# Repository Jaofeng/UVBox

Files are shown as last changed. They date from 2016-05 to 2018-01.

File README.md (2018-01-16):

# 自製 UV 紫外線曝光控制器
本控制器以 Arduino 的 ATMEGA328P 為核心，控制 UV LED 燈板，作為 DIY PCB 曝光用。

## 目錄
* [控制器硬體概要說明](#控制器硬體概要說明)
* [Arduino 程式功能](#arduino-程式功能)
* [原理圖與板線圖](#原理圖與板線圖)
* [實做範例](#實做範例)

## 控制器硬體概要說明
控制器分為兩版本：595 版與 I2C LCD 版。  
兩版本電路、功能都大同小異，最大差別在於 595 版是使用 74x595 控制七段顯示器作為顯示；I2C LCD 則是使用 PCF8574 控制 1602 的 LCD(相容HD44780)。  
I2C LCD 版提供 USB 界面(使用 FT232R)，可直接修改 Arduino 程式；而 595 版本就必須使用 ICSP 界面進行更新。

使用 4 + 1 個按鍵共 5 個按鍵進行控制：
* Start : 開始曝光
* Mode : 選擇模式  
    * 同時點亮上下兩板  
    * 僅點亮上板  
    * 僅點亮下板  
    * 亮度調整模式  
* Up / Dn :  
    * 亮度調整模式：增加/減少亮度值，增減量 +/- 5%
    * 其餘模式：增加/減少秒數，增減量 10 秒
* Reset : 重新啟動

595 版是第一個版本，小弟先用麵包版電路作第一片 595 版的 PCB，再用他去做其他的 PCB。

使用一般 Notebook 電源供應器(DC 19V)做為電源輸入，由於電路主要電壓使用 5V，為避免壓差太大，造成降壓晶片過熱燒毀，所以我做了兩次降壓：19v -> 12v -> 5v。  
由 ULN2003 控制 UV LED 燈板，也就是燈板部分直接使用 19V 電源。

在此不提供 UV LED 燈板的電路，我使用 5 串 1 並 14 的方式組成一片燈板，意思就是 5 顆 UV LED 與 1 顆限流電阻為一組做串聯，一共有 14 組併聯(請參閱下方照片)。    
LED 間距約為 7 x 2.54 mm。

依 LED 編排密度、曝光亮度、燈板高度、線路複雜度、感光 PCB 有效期、遮色片材質等等因素，都會互相影響，所以建議各位自行實驗，找出適合的亮度、時間與燈板高度。

以小弟的經驗是：
* 線路片使用噴墨投影片，兩張重疊，增加黑色遮光效果
* 燈板高度約 7cm
* 亮度 70%
* 時間 90s~110s 不等

以上述條件，即可成功製作一片漂亮的 PCB 線路。

對了，很基本的一件事：遮色片與感光 PCB 一定要夾緊，不能有任何間隙，否則非常容易失敗。

還有，UV 紫外線很傷眼睛，為了您的眼睛著想，建議戴著抗 UV 的鏡片，以及也不要讓皮膚長時間曝曬紫外線的環境下喔... 

***

## Arduino 程式功能
開始曝光後，會顯示倒數時間，曝光時間結束時會將燈板關閉且蜂鳴器會發出警示音。

控制功能：
* 可單一控制上下燈板
* 亮度調整範圍自 0% ~ 100%
* 時間可調整範圍自 0s ~ 600s
* 曝光時間結束時，自動關閉光板，並響起警示音
* 警示音響起時，按任何一鍵停止響音

***
## 原理圖與板線圖
595版  
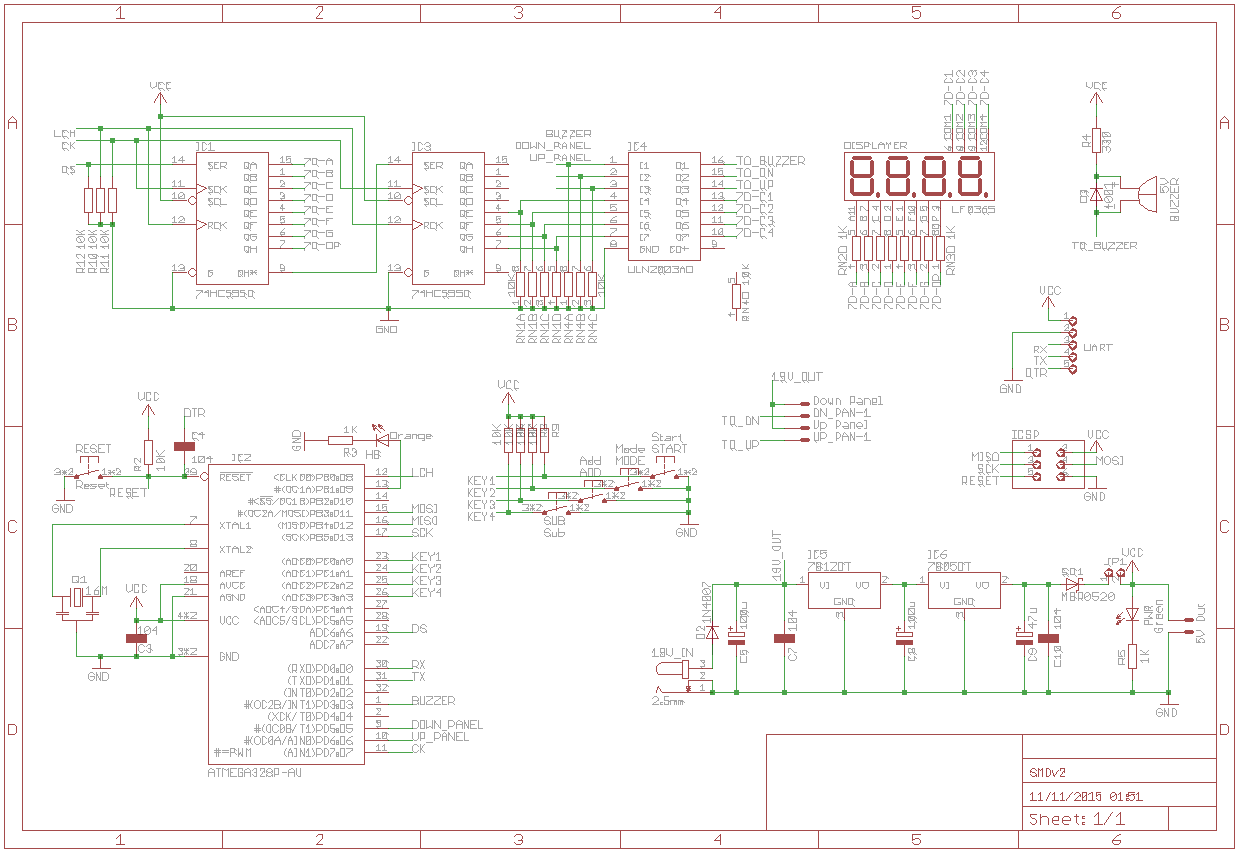
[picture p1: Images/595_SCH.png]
595 版原理圖

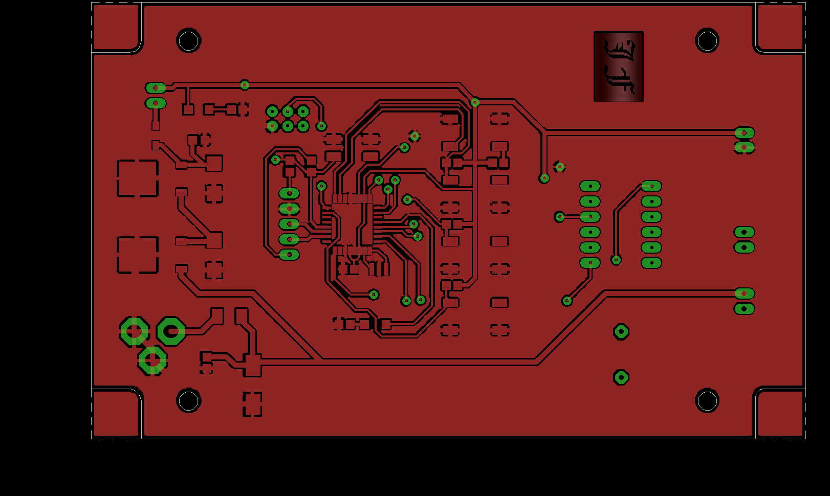
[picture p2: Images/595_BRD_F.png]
595 正面板線圖

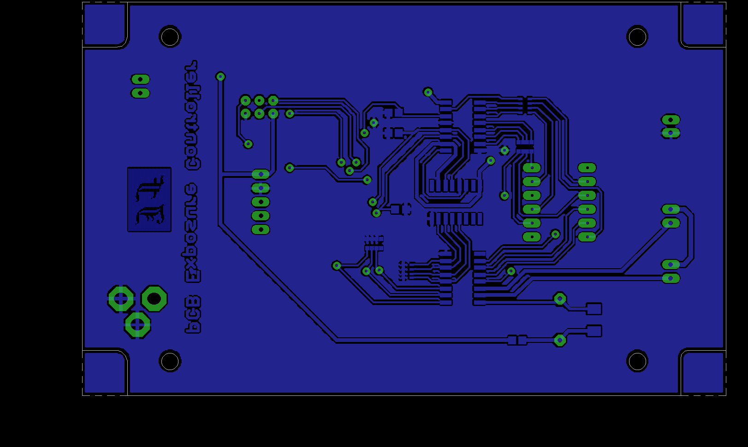
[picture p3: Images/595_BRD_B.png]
595 背面板線圖


I2C LCD版  
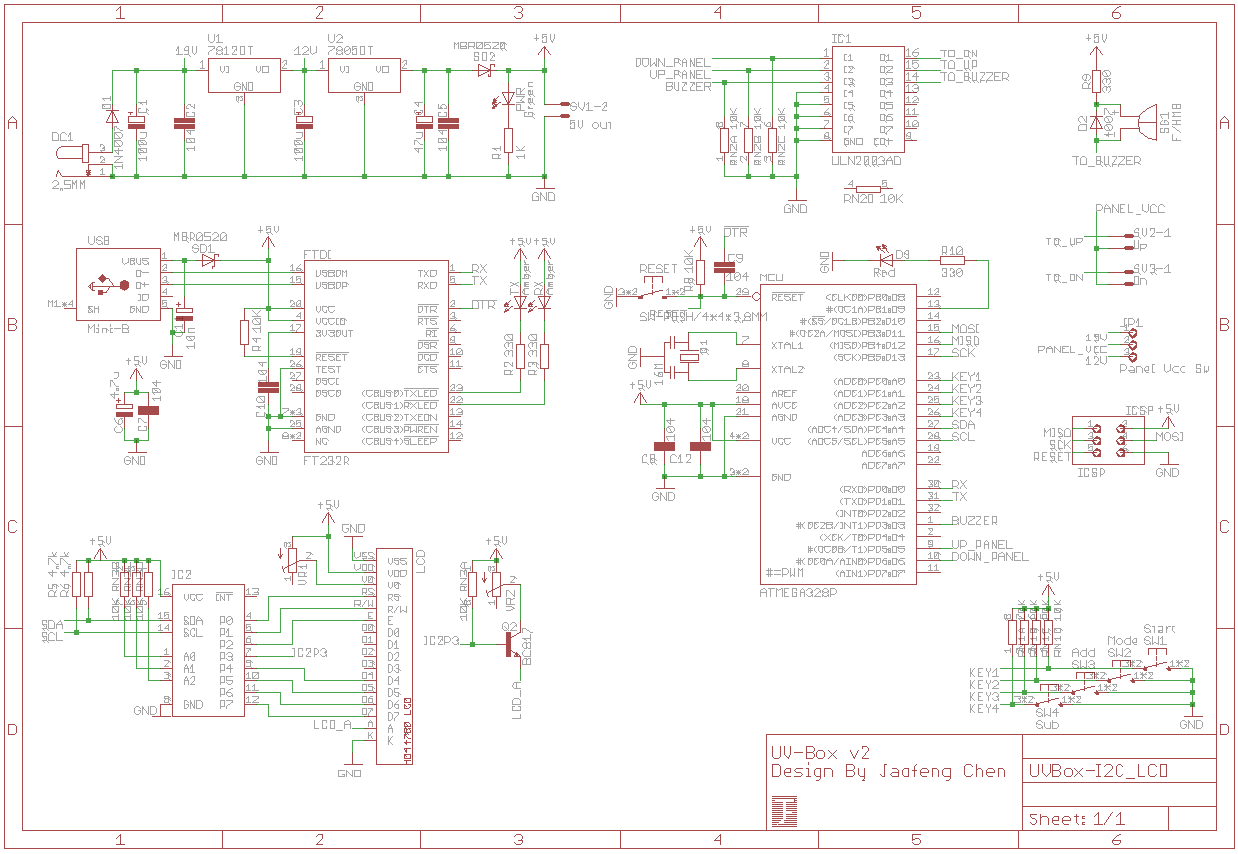
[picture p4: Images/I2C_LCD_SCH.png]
I2C LCD 版原理圖

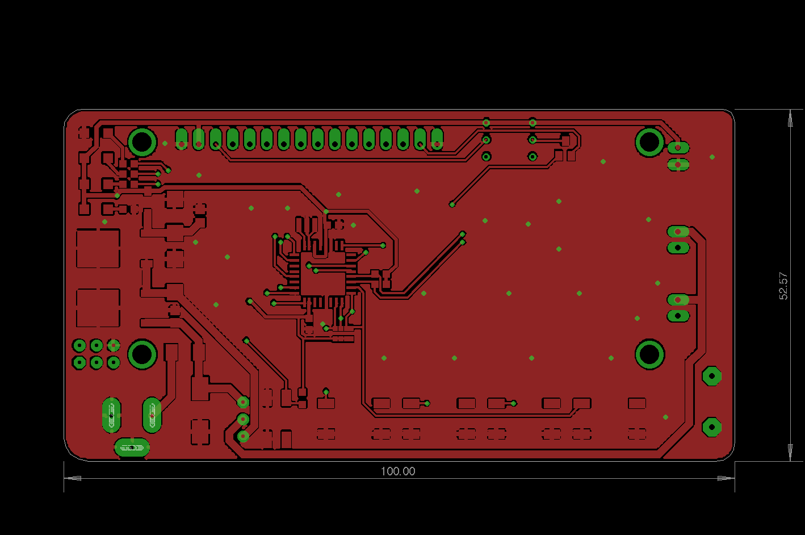
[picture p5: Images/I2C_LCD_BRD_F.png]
I2C LCD 正面板線圖

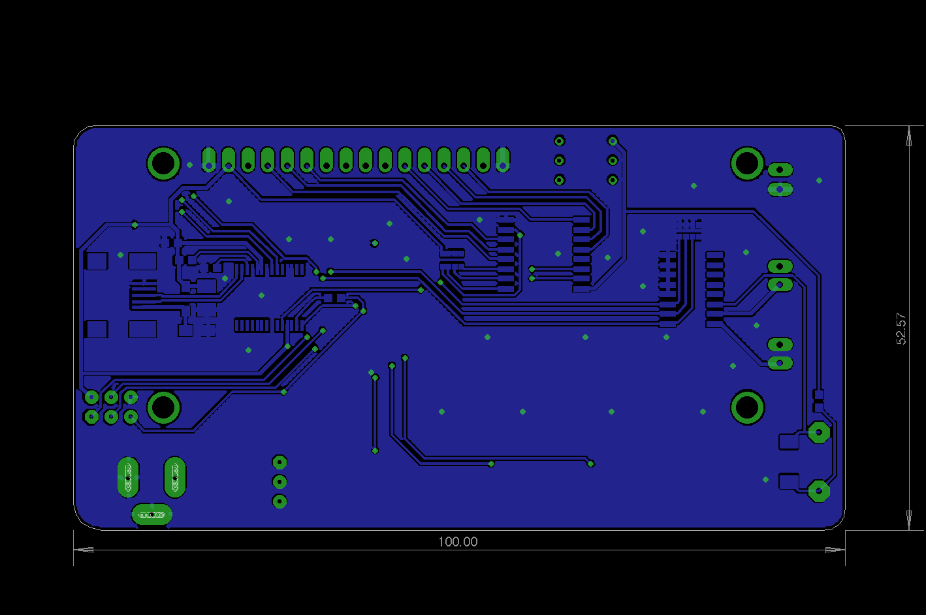
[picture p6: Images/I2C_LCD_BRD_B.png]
I2C LCD 背面板線圖


***
## 實做範例
UV LED 燈板與控制板(595)    
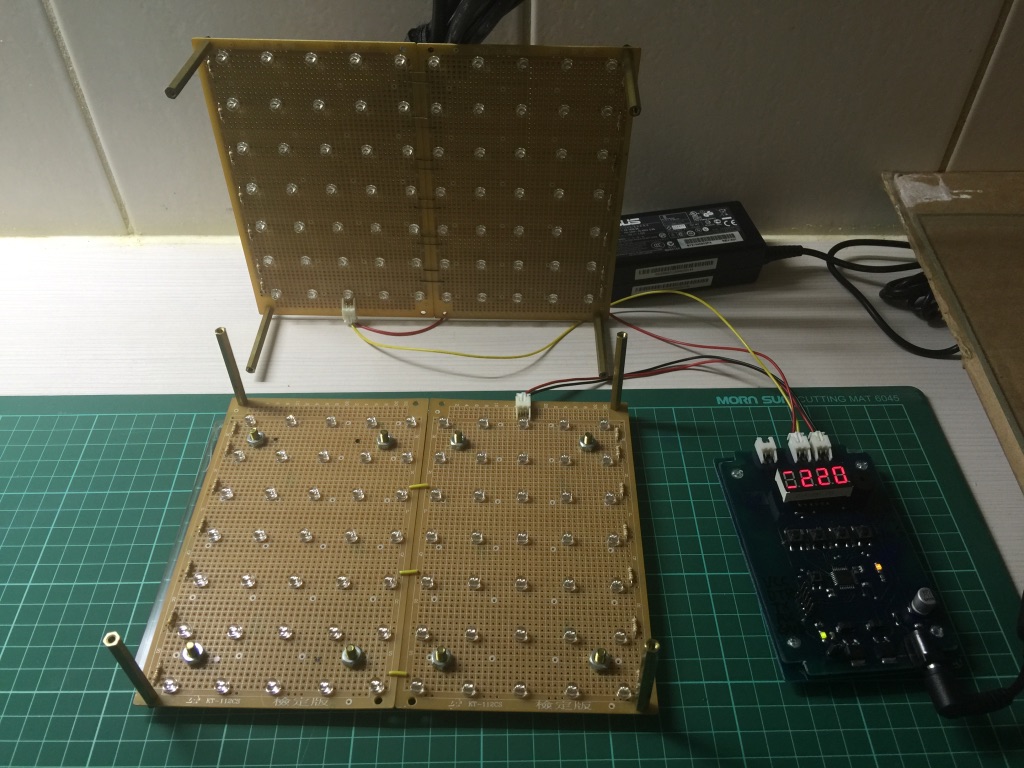
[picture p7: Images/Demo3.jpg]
燈板與控制板(未亮)
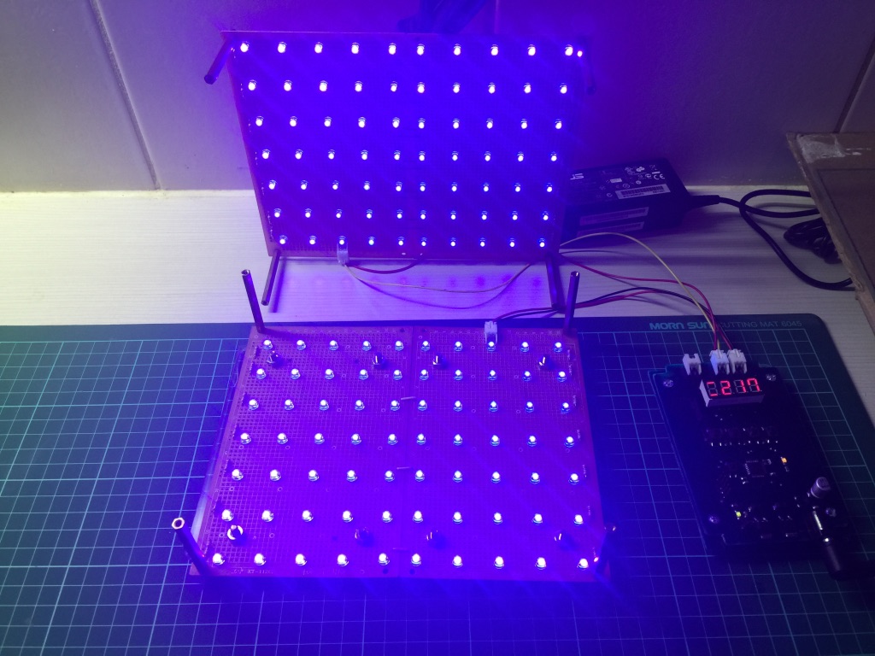
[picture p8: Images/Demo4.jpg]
燈板與控制板(點亮)
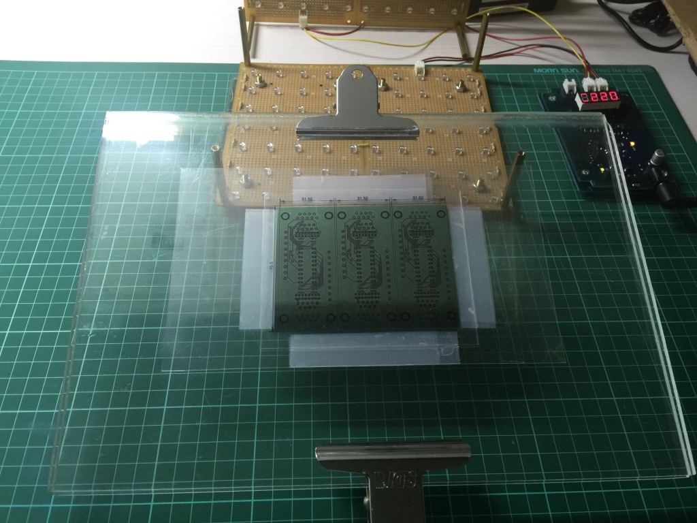
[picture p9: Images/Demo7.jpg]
底片與壓克力夾板
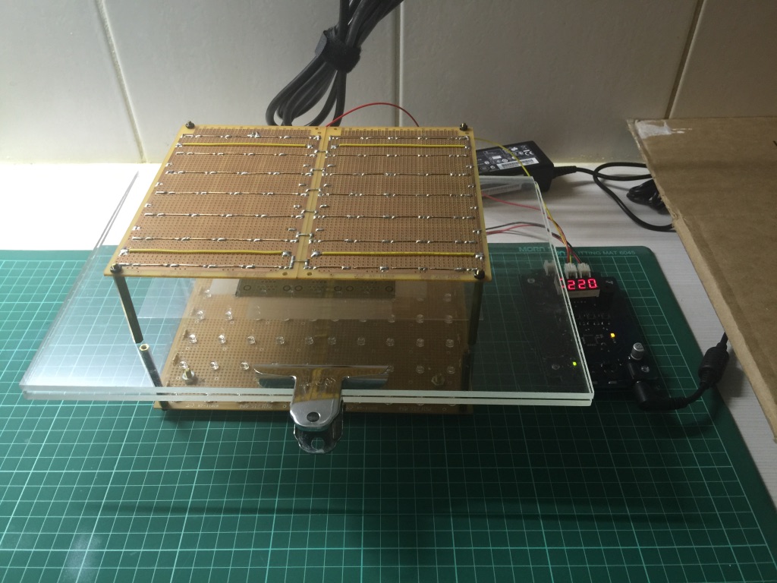
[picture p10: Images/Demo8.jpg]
燈板與壓克力夾板放置位置
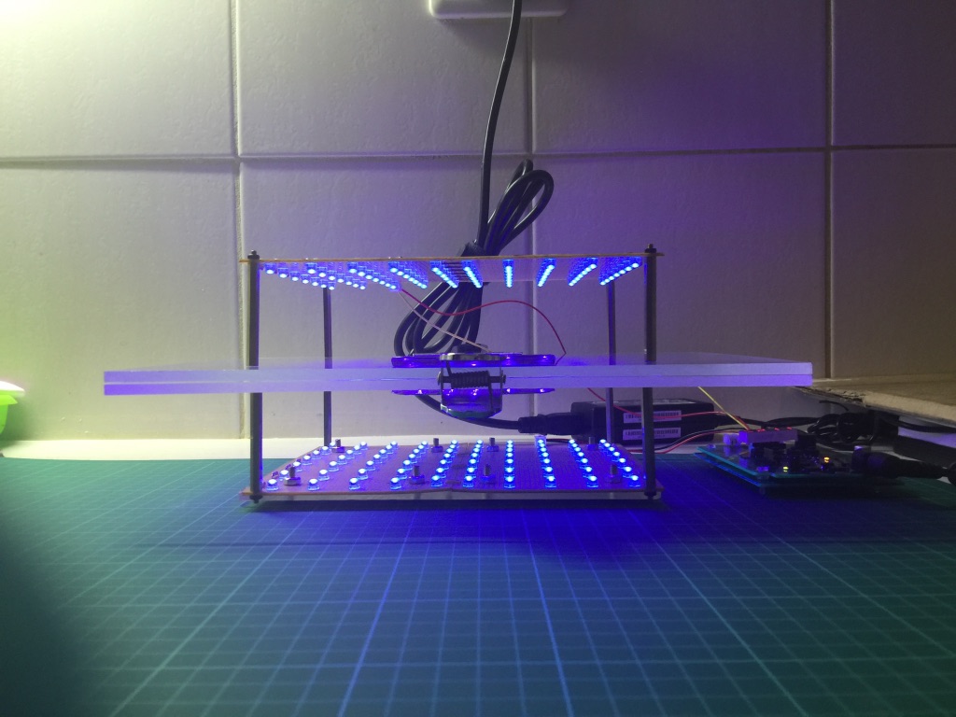
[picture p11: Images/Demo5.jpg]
曝光中-側面
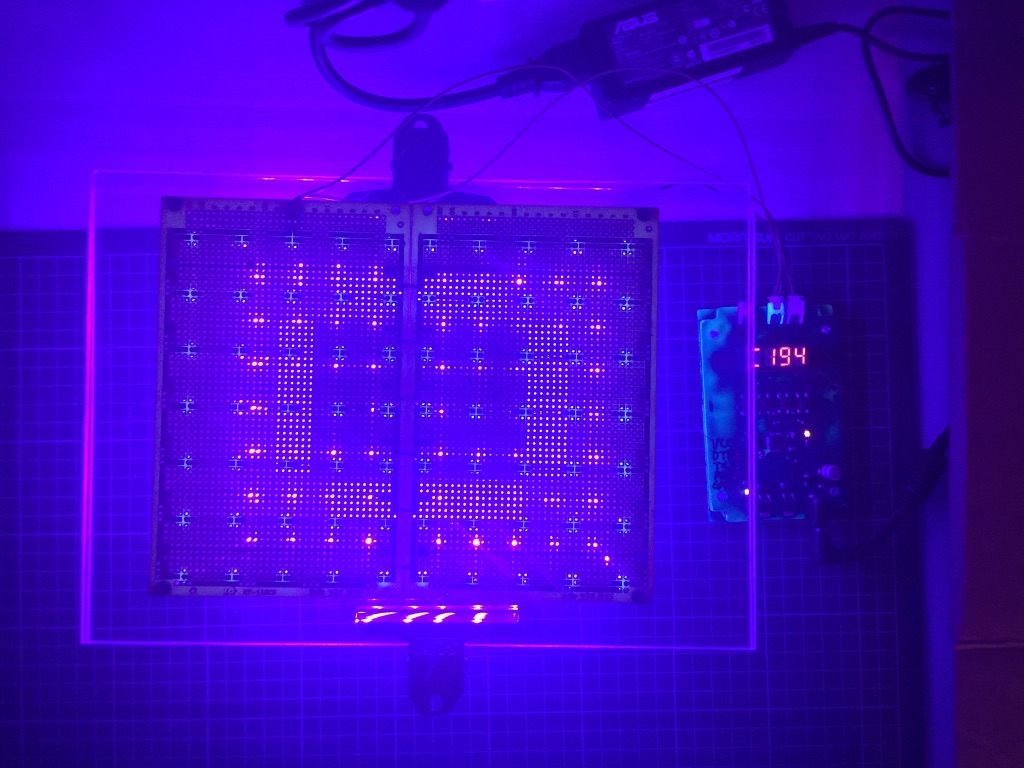
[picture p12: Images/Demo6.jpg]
曝光中-俯視


595 版正反面    
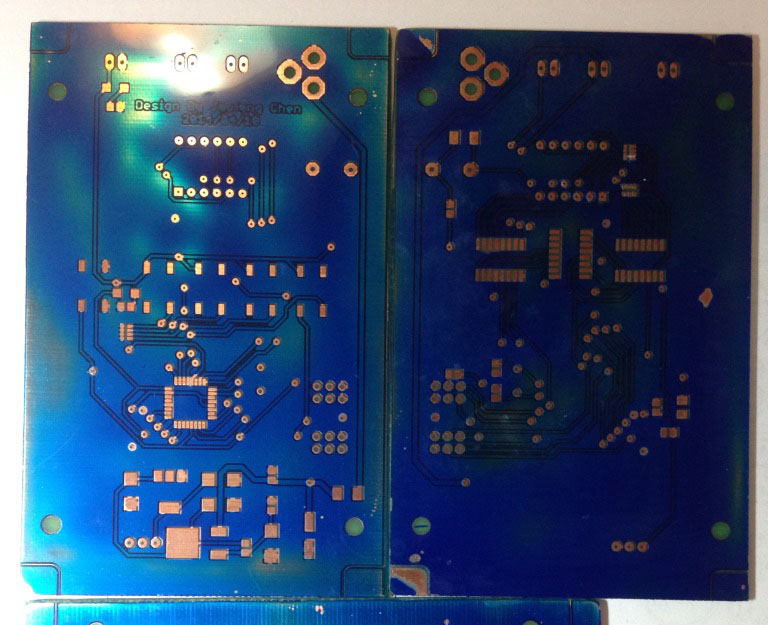
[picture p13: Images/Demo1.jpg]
595版正反面
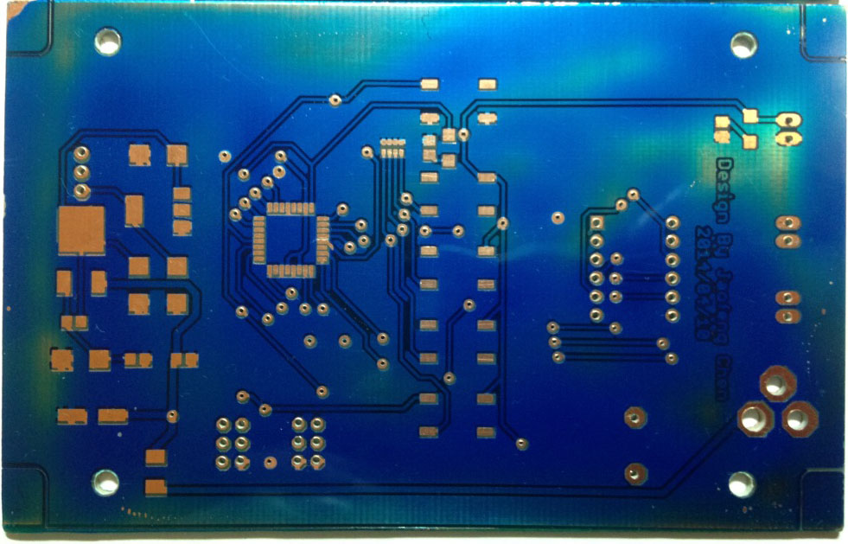
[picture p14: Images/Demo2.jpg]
595版正面


自製 USB to UART 轉接板    
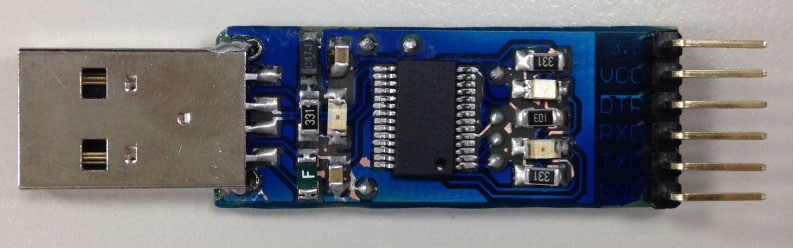
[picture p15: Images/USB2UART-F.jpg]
USB to UART 正面
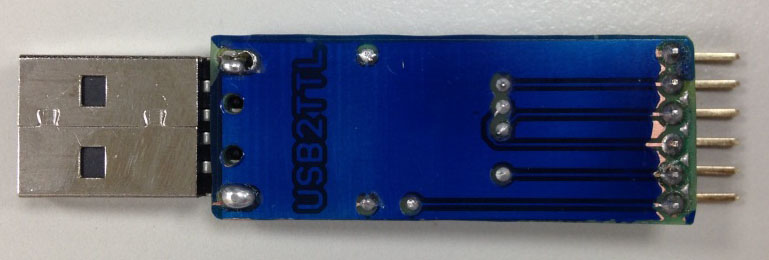
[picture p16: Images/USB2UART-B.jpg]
USB to UART 背面


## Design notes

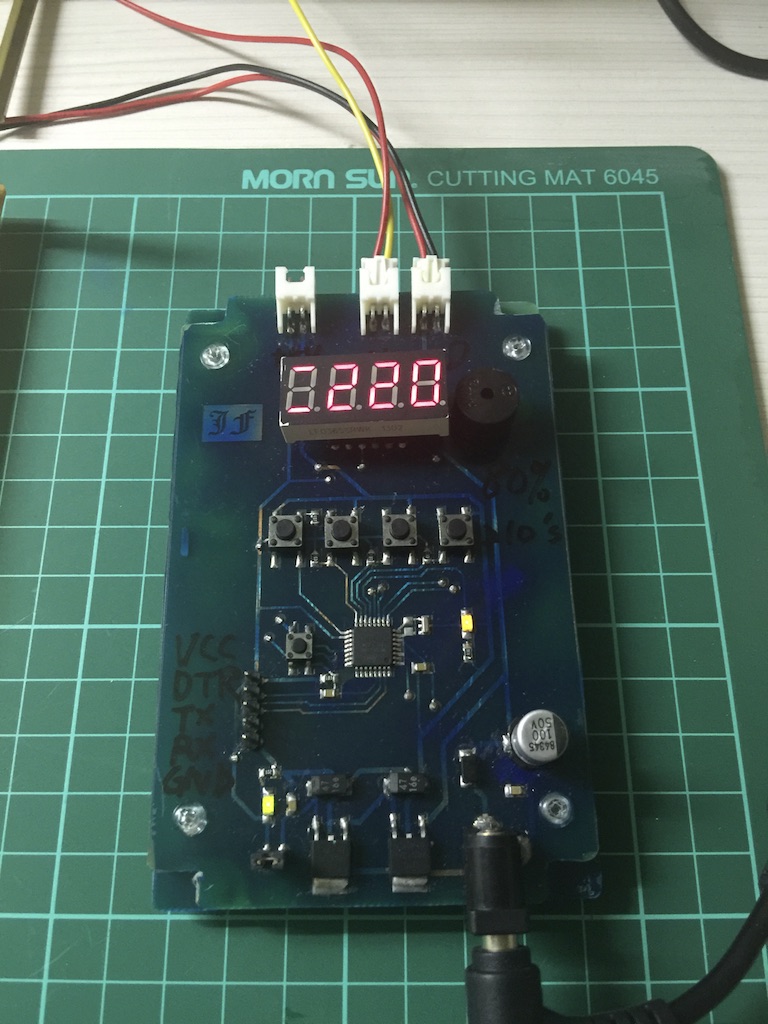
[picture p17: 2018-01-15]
Images/Demo9.jpg

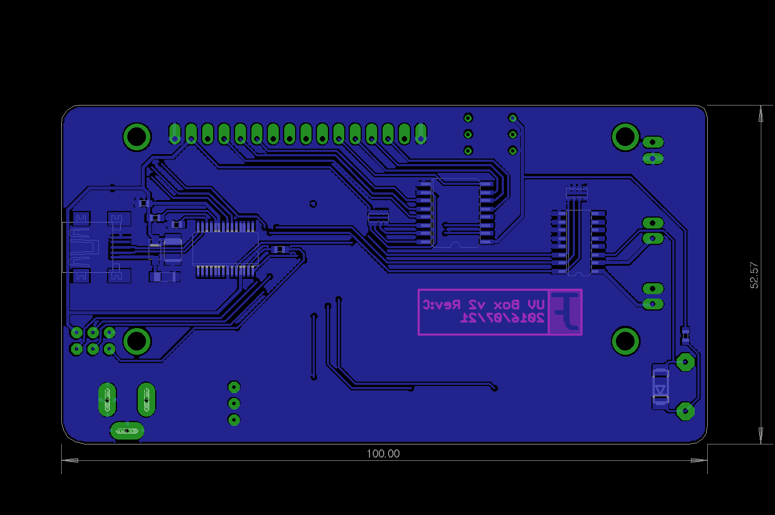
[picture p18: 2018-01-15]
Images/I2C_LCD_BRD_Layout_B.png

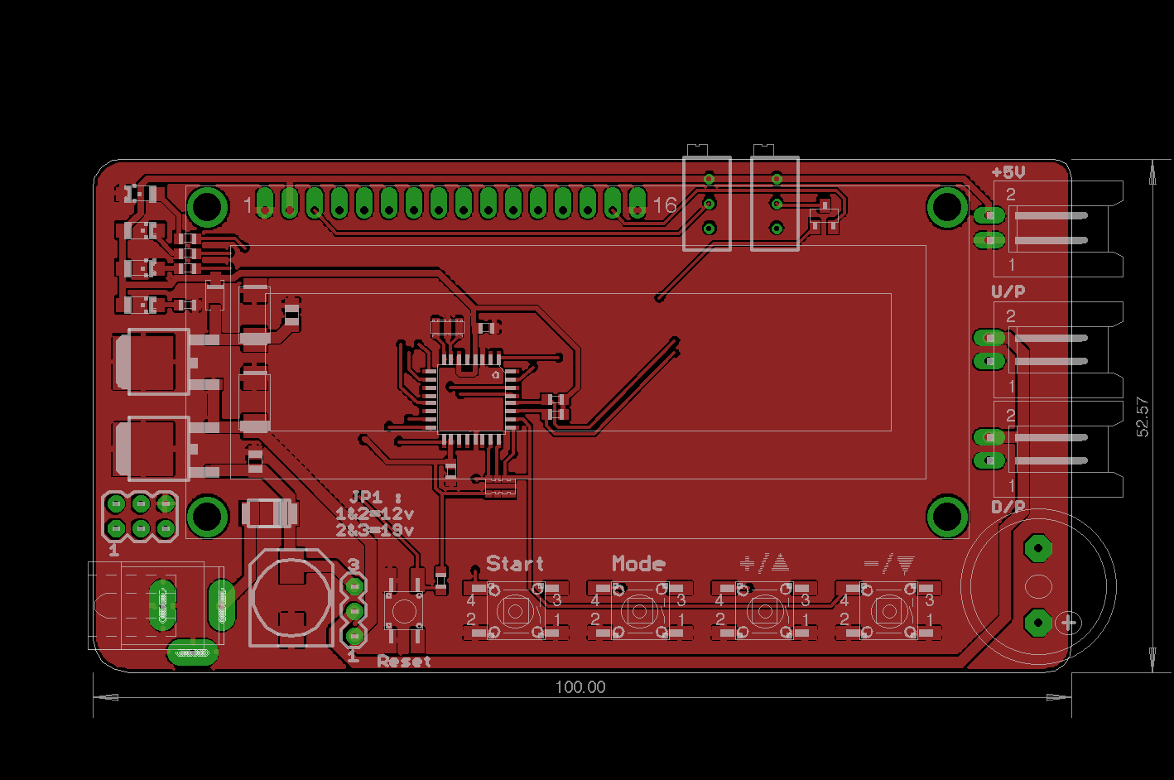
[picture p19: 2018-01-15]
Images/I2C_LCD_BRD_Layout_F.png

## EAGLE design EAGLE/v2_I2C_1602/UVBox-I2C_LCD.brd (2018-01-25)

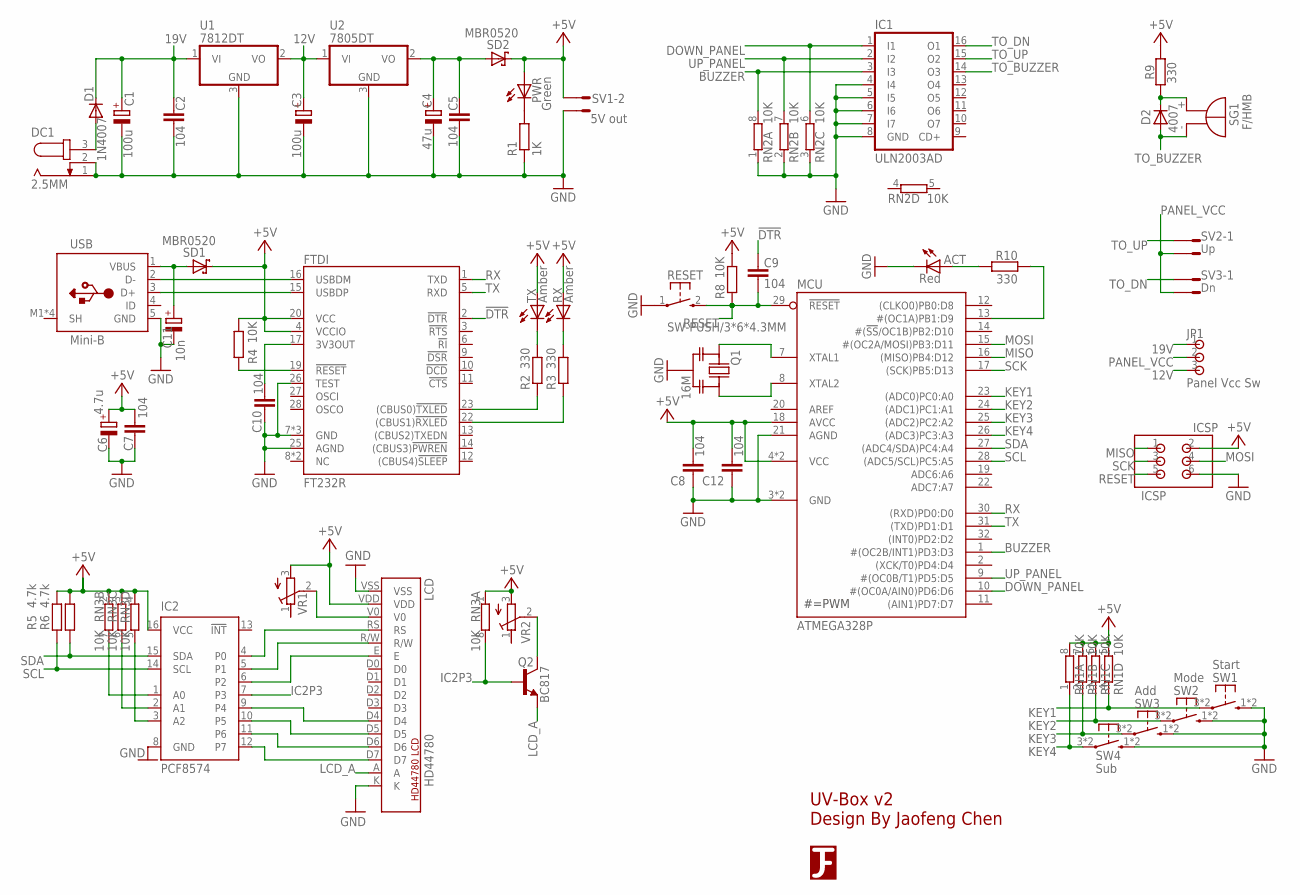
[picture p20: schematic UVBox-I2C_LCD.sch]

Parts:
ACT: Red; CHIPLED_0805
C1: 100u; 140CLH-0810
C2, C5: 104; C0805
C3: 100u; SMC_C
C4: 47u; SMC_C
C6: 4.7u; SMC_B
C7, C8, C9, C10, C12: 104; C0603
C11: 10n; SMC_A
D1: 1N4007; DO-214AC
D2: 4007; DO214AA
DC1: 2.5MM; SPC4078
FTDI: FT232R; SSOP28
IC1: ULN2003AD; SO16(R-PDSO-G16)
IC2: PCF8574; SO16W
ICSP: ICSP; DIP-2.54-2X3
JP1: Panel Vcc Sw; DIP-2.54-1X3
LCD: HD44780; LCD_1602
MCU: ATMEGA328P; TQFP32
PWR: Green; CHIPLED_0805
Q1: 16M; CSTCE
Q2: BC817; SOT23-BEC
R1: 1K; R0603
R2, R3, R9, R10: 330; R0603
R4, R8: 10K; R0603
R5, R6: 4.7k; R0603
RESET: SW-PUSH/3*6*4.3MM; SW-3*6*4.3MM
RN1, RN2, RN3: 10K; CAY16
RX: Amber; CHIPLED_0805
SD1, SD2: MBR0520; SOD123
SG1: F/HMB
SV1: 5V out; L02P
SV2: Up; L02P
SV3: Dn; L02P
SW1: Start; SW-6*6*3.8MM
SW2: Mode; SW-6*6*3.8MM
SW3: Add; SW-6*6*3.8MM
SW4: Sub; SW-6*6*3.8MM
TX: Amber; CHIPLED_0805
U1: 7812DT; TO252
U2: 7805DT; TO252
U$2: LOGO-3B; LOGO-3-B
USB: Mini-B; USB-MINI-B(NO_HOLE)
VR1, VR2: R-TRIMMT93XA; RTRIMT93XA

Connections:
12V: C3.+, JP1.3, U1.2 (VO), U2.1 (VI)
19V: C1.+, C2.1, D1.C, JP1.1, U1.1 (VI)
!DTR: C9.2, FTDI.2 (!DTR)
!RESET: FTDI.19 (!RESET), R4.1
!RXLED: FTDI.22 ((CBUS1)!RXLED), R3.1
!TXLED: FTDI.23 ((CBUS0)!TXLED), R2.1
+5V: C6.+, C7.1, C8.2, C12.2, FTDI.4 (VCCIO), FTDI.20 (VCC), IC2.16 (VCC), ICSP.2, LCD.VDD, MCU.4 (VCC), MCU.6 (VCC), MCU.18 (AVCC), PWR.A, R4.2, R5.1, R6.1, R8.2, R9.2, RN1.5 (2), RN1.6 (2), RN1.7 (2), RN1.8 (2), RN3.1, RN3.2 (1), RN3.3 (1), RN3.4 (1), RX.A, SD1.K, SD2.K, SV1.2, TX.A, VR1.3 (A), VR2.3 (A)
A0: IC2.1 (A0), RN3.7 (2)
A1: IC2.2 (A1), RN3.6 (2)
A2: IC2.3 (A2), RN3.5 (2)
ACT_LED: ACT.A, R10.2
BUZZER: IC1.3 (I3), MCU.1 (#(OC2B/INT1)PD3:D3), RN2.8 (2)
D+: FTDI.15 (USBDP), USB.3 (D+)
D-: FTDI.16 (USBDM), USB.2 (D-)
DOWN_PANEL: IC1.1 (I1), MCU.10 (#(OC0A/AIN0)PD6:D6), RN2.6 (2)
E: IC2.6 (P2), LCD.E
GND: ACT.C, C1.-, C2.2, C3.-, C4.-, C5.2, C6.-, C7.2, C8.1, C10.1, C11.-, C12.1, DC1.1, DC1.2, FTDI.7 (GND), FTDI.18 (GND), FTDI.21 (GND), FTDI.25 (AGND), FTDI.26 (TEST), IC1.4 (I4), IC1.5 (I5), IC1.6 (I6), IC1.7 (I7), IC1.8 (GND), IC2.8 (GND), ICSP.6, LCD.K, LCD.VSS, MCU.3 (GND), MCU.5 (GND), MCU.21 (AGND), Q1.2 (GND), R1.1, RESET.1, RN2.1, RN2.2 (1), RN2.3 (1), SV1.1, SW1.1 (S), SW1.2 (S), SW2.1 (S), SW2.2 (S), SW3.1 (S), SW3.2 (S), SW4.1 (S), SW4.2 (S), U1.3 (GND), U2.3 (GND), USB.5 (GND)
IC2P3: IC2.7 (P3), Q2.B, RN3.8 (2)
KEY1: MCU.23 ((ADC0)PC0:A0), RN1.4 (1), SW1.3, SW1.4
KEY2: MCU.24 ((ADC1)PC1:A1), RN1.3 (1), SW2.3, SW2.4
KEY3: MCU.25 ((ADC2)PC2:A2), RN1.2 (1), SW3.3, SW3.4
KEY4: MCU.26 ((ADC3)PC3:A3), RN1.1, SW4.3, SW4.4
LCD_A: LCD.A, Q2.E
MISO: ICSP.1, MCU.16 ((MISO)PB4:D12)
MOSI: ICSP.4, MCU.15 (#(OC2A/MOSI)PB3:D11)
unnamed: C11.+, SD1.A, USB.1 (VBUS)
unnamed: C4.+, C5.1, SD2.A, U2.2 (VO)
unnamed: D1.A, DC1.3
unnamed: PWR.C, R1.2
unnamed: Q2.C, VR2.2 (S)
unnamed: R2.2, TX.C
unnamed: R3.2, RX.C
unnamed: D2.C, R9.1, SG1.+
unnamed: IC2.12 (P7), LCD.D7
unnamed: IC2.11 (P6), LCD.D6
unnamed: IC2.10 (P5), LCD.D5
unnamed: IC2.9 (P4), LCD.D4
unnamed: C10.2, FTDI.17 (3V3OUT)
PANEL_VCC: JP1.2, SV2.2, SV3.2
PB1: MCU.13 (#(OC1A)PB1:D9), R10.1
R/W: IC2.5 (P1), LCD.R/W
RESET: C9.1, ICSP.5, MCU.29 (!RESET), R8.1, RESET.2 (S)
RS: IC2.4 (P0), LCD.RS
RX: FTDI.1 (TXD), MCU.30 ((RXD)PD0:D0)
SCK: ICSP.3, MCU.17 ((SCK)PB5:D13)
SCL: IC2.14 (SCL), MCU.28 ((ADC5/SCL)PC5:A5), R5.2
SDA: IC2.15 (SDA), MCU.27 ((ADC4/SDA)PC4:A4), R6.2
TO_BUZZER: D2.A, IC1.14 (O3), SG1.-
TO_DN: IC1.16 (O1), SV3.1
TO_UP: IC1.15 (O2), SV2.1
TX: FTDI.5 (RXD), MCU.31 ((TXD)PD1:D1)
UP_PANEL: IC1.2 (I2), MCU.9 (#(OC0B/T1)PD5:D5), RN2.7 (2)
VD: LCD.V0, VR1.2 (S)
XTAL1: MCU.7 (XTAL1), Q1.1 (IN)
XTAL2: MCU.8 (XTAL2), Q1.3 (OUT)

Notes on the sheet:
UV-Box v2 Design By Jaofeng Chen

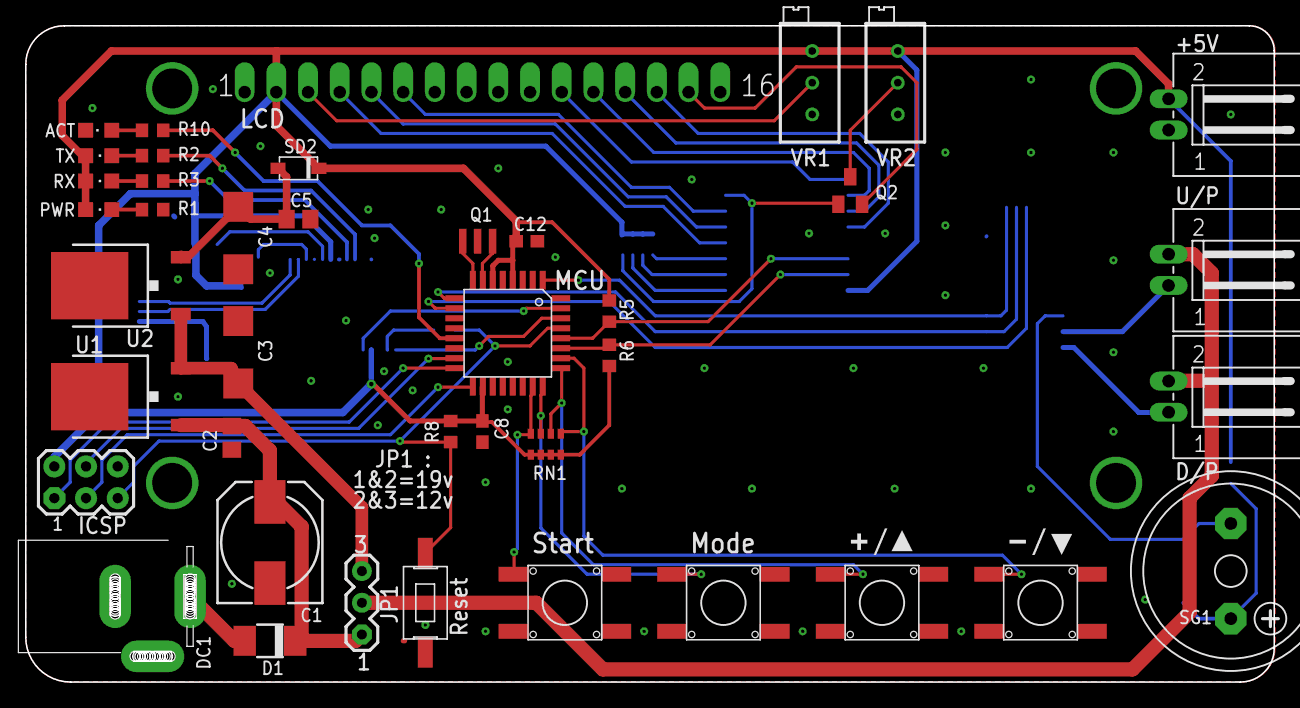
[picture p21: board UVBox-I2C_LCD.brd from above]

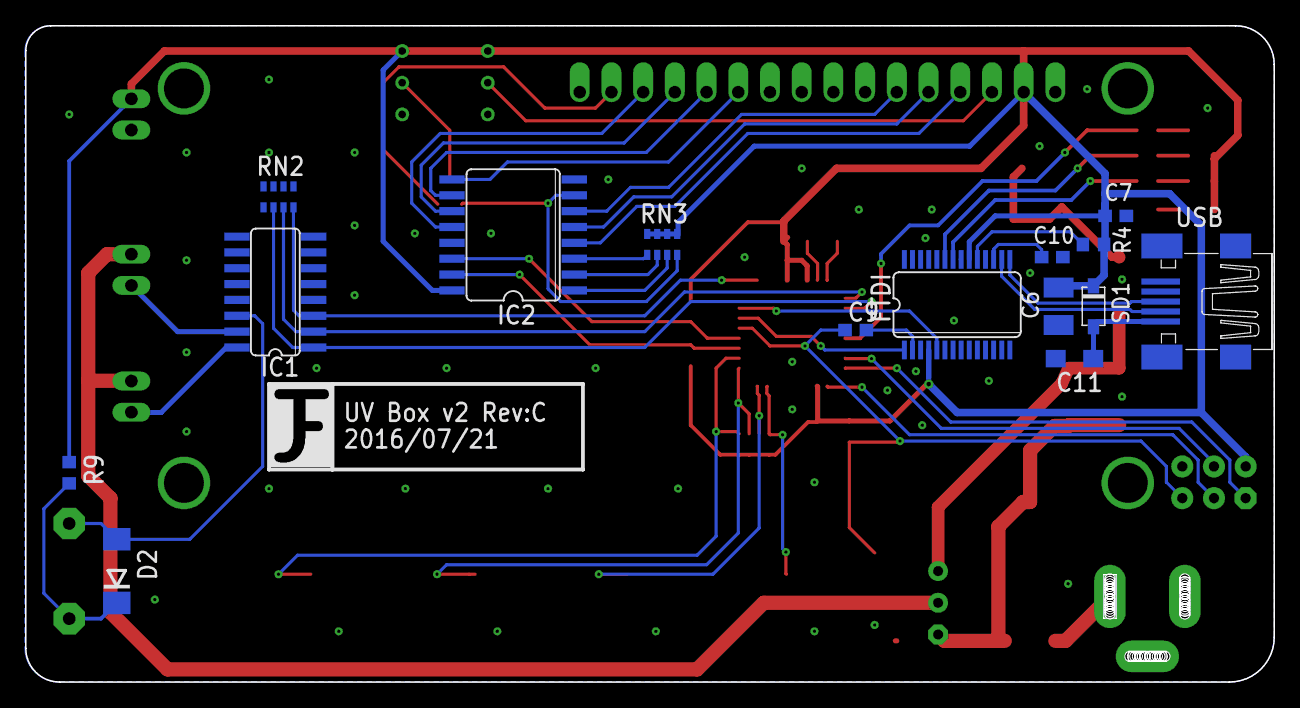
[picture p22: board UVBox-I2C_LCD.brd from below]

Board: 2 copper layers, 100.0 x 52.6 mm, 59 parts (15 on the bottom side), 55 nets.

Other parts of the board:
U$1: TEXT_UP
U$3: TEXT_DN

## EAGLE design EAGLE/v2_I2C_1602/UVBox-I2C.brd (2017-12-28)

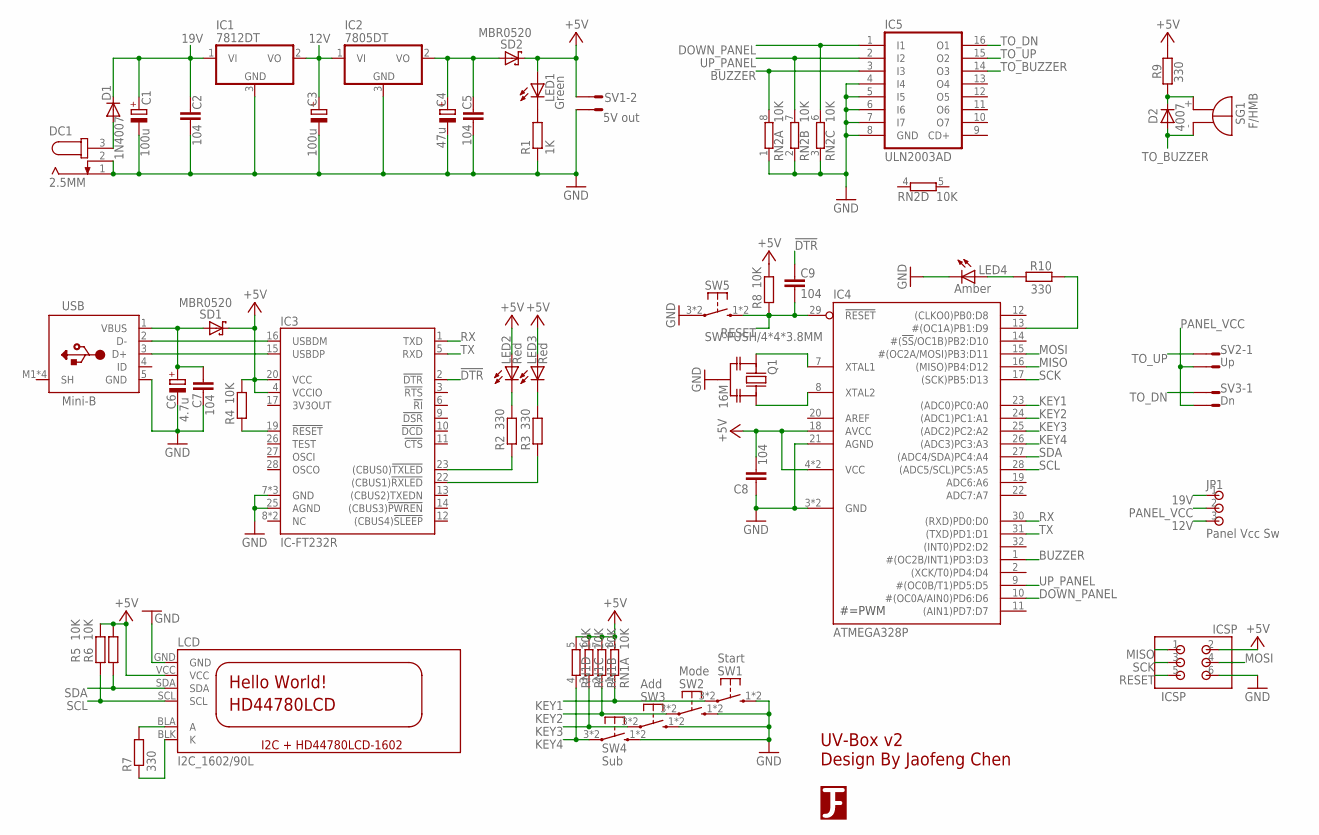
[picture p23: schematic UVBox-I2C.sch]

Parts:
C1: 100u; 140CLH-0810
C2, C5, C7, C8, C9: 104; C0805
C3: 100u; SMC_C
C4: 47u; SMC_C
C6: 4.7u; SMC_C
D1: 1N4007; DO-214AC
D2: 4007; DO214AA
DC1: 2.5MM; SPC4078
IC1: 7812DT; TO252
IC2: 7805DT; TO252
IC3: IC-FT232R; SSOP28
IC4: ATMEGA328P; TQFP32
IC5: ULN2003AD; SO16
ICSP: ICSP; DIP-2.54-2X3
JP1: Panel Vcc Sw; DIP-2.0-1X3
LCD: I2C_1602/90L
LED1: Green; CHIPLED_1206
LED2, LED3: Red; CHIPLED_1206
LED4: Amber; CHIPLED_1206
Q1: 16M; CSTCE
R1: 1K; R0805
R2, R3, R7, R9, R10: 330; R0805
R4, R5, R6, R8: 10K; R0805
RN1, RN2: 10K; CAY16
SD1, SD2: MBR0520; SOD123
SG1: F/HMB
SV1: 5V out; L02P
SV2: Up; L02P
SV3: Dn; L02P
SW1: Start; SW-6*6*3.8MM
SW2: Mode; SW-6*6*3.8MM
SW3: Add; SW-6*6*3.8MM
SW4: Sub; SW-6*6*3.8MM
SW5: SW-PUSH/4*4*3.8MM; SW-4*4*3.8MM
U$2: LOGO-3
USB: Mini-B; USB-MINI-B(NO_HOLE)

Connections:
12V: C3.+, IC1.2 (VO), IC2.1 (VI), JP1.3
19V: C1.+, C2.1, D1.C, IC1.1 (VI), JP1.1
!DTR: C9.2, IC3.2 (!DTR)
+5V: C8.2, IC3.4 (VCCIO), IC3.20 (VCC), IC4.4 (VCC), IC4.6 (VCC), IC4.18 (AVCC), ICSP.2, LCD.VCC, LED1.A, LED2.A, LED3.A, R4.2, R5.1, R6.1, R8.2, R9.2, RN1.5 (2), RN1.6 (2), RN1.7 (2), RN1.8 (2), SD1.K, SD2.K, SV1.2
BUZZER: IC4.1 (#(OC2B/INT1)PD3:D3), IC5.3 (I3), RN2.8 (2)
DOWN_PANEL: IC4.10 (#(OC0A/AIN0)PD6:D6), IC5.1 (I1), RN2.6 (2)
GND: C1.-, C2.2, C3.-, C4.-, C5.2, C6.-, C7.2, C8.1, DC1.1, DC1.2, IC1.3 (GND), IC2.3 (GND), IC3.7 (GND), IC3.18 (GND), IC3.21 (GND), IC3.25 (AGND), IC4.3 (GND), IC4.5 (GND), IC4.21 (AGND), IC5.4 (I4), IC5.5 (I5), IC5.6 (I6), IC5.7 (I7), IC5.8 (GND), ICSP.6, LCD.GND, LED4.C, Q1.2 (GND), R1.1, RN2.1, RN2.2 (1), RN2.3 (1), SV1.1, SW1.1 (S), SW1.2 (S), SW2.1 (S), SW2.2 (S), SW3.1 (S), SW3.2 (S), SW4.1 (S), SW4.2 (S), SW5.3, SW5.4, USB.5 (GND)
KEY1: IC4.23 ((ADC0)PC0:A0), RN1.1, SW1.3, SW1.4
KEY2: IC4.24 ((ADC1)PC1:A1), RN1.2 (1), SW2.3, SW2.4
KEY3: IC4.25 ((ADC2)PC2:A2), RN1.3 (1), SW3.3, SW3.4
KEY4: IC4.26 ((ADC3)PC3:A3), RN1.4 (1), SW4.3, SW4.4
MISO: IC4.16 ((MISO)PB4:D12), ICSP.1
MOSI: IC4.15 (#(OC2A/MOSI)PB3:D11), ICSP.4
unnamed: C6.+, C7.1, SD1.A, USB.1 (VBUS)
unnamed: C4.+, C5.1, IC2.2 (VO), SD2.A
unnamed: D1.A, DC1.3
unnamed: IC3.19 (!RESET), R4.1
unnamed: IC4.7 (XTAL1), Q1.1 (IN)
unnamed: LED1.C, R1.2
unnamed: IC3.16 (USBDM), USB.2 (D-)
unnamed: LCD.BLK (K), R7.1
unnamed: LCD.BLA (A), R7.2
unnamed: IC3.15 (USBDP), USB.3 (D+)
unnamed: LED2.C, R2.2
unnamed: LED3.C, R3.2
unnamed: D2.C, R9.1, SG1.+
unnamed: IC3.23 ((CBUS0)!TXLED), R2.1
unnamed: IC3.22 ((CBUS1)!RXLED), R3.1
unnamed: LED4.A, R10.2
unnamed: IC4.13 (#(OC1A)PB1:D9), R10.1
unnamed: IC4.8 (XTAL2), Q1.3 (OUT)
PANEL_VCC: JP1.2, SV2.2, SV3.2
RESET: C9.1, IC4.29 (!RESET), ICSP.5, R8.1, SW5.1 (S), SW5.2 (S)
RX: IC3.1 (TXD), IC4.30 ((RXD)PD0:D0)
SCK: IC4.17 ((SCK)PB5:D13), ICSP.3
SCL: IC4.28 ((ADC5/SCL)PC5:A5), LCD.SCL, R5.2
SDA: IC4.27 ((ADC4/SDA)PC4:A4), LCD.SDA, R6.2
TO_BUZZER: D2.A, IC5.14 (O3), SG1.-
TO_DN: IC5.16 (O1), SV3.1
TO_UP: IC5.15 (O2), SV2.1
TX: IC3.5 (RXD), IC4.31 ((TXD)PD1:D1)
UP_PANEL: IC4.9 (#(OC0B/T1)PD5:D5), IC5.2 (I2), RN2.7 (2)

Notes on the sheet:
UV-Box v2 Design By Jaofeng Chen

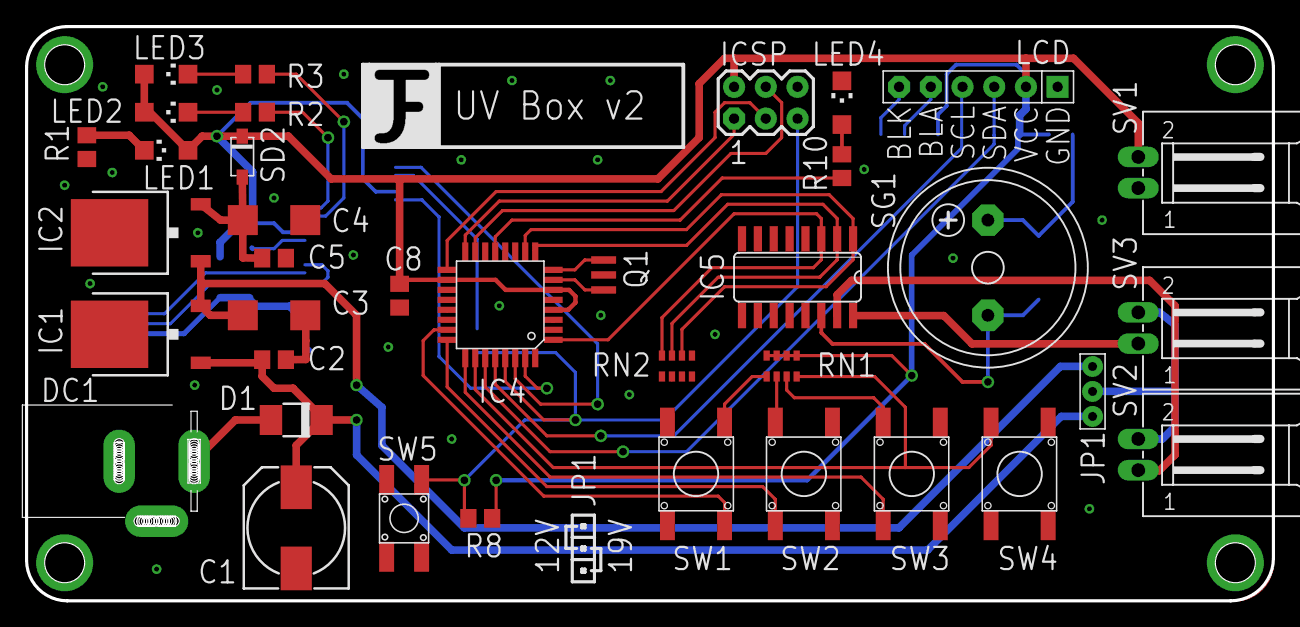
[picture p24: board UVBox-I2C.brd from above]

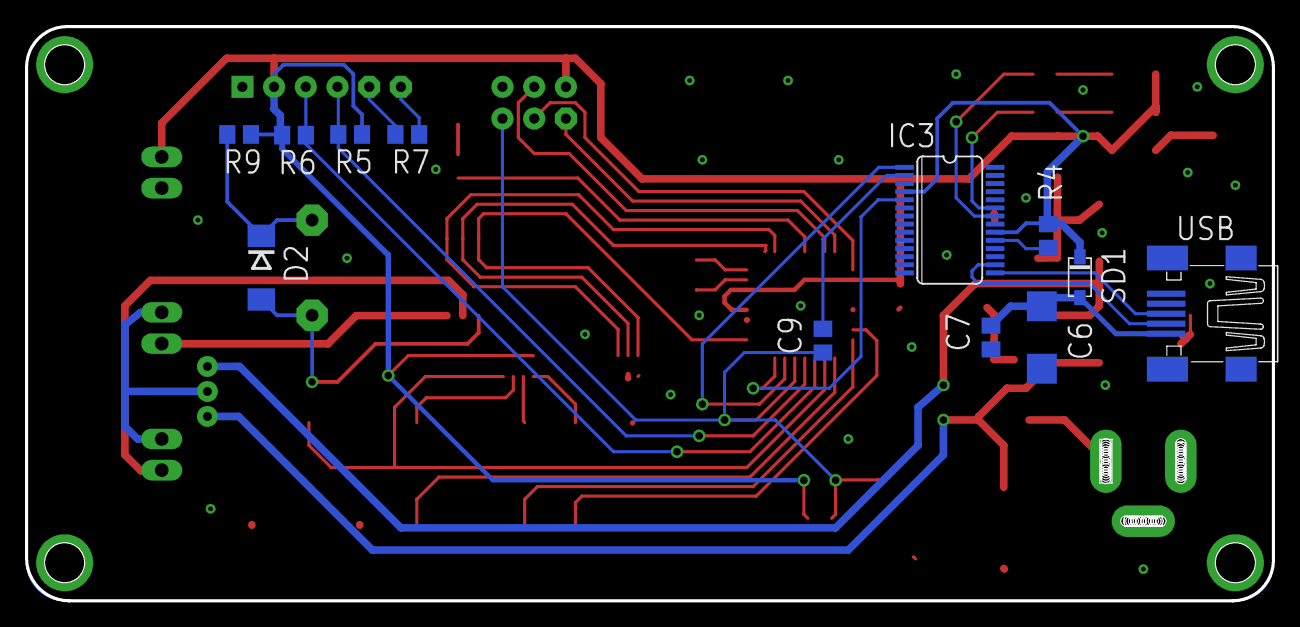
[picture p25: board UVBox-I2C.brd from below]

Board: 2 copper layers, 99.8 x 46.0 mm, 50 parts (12 on the bottom side), 42 nets.

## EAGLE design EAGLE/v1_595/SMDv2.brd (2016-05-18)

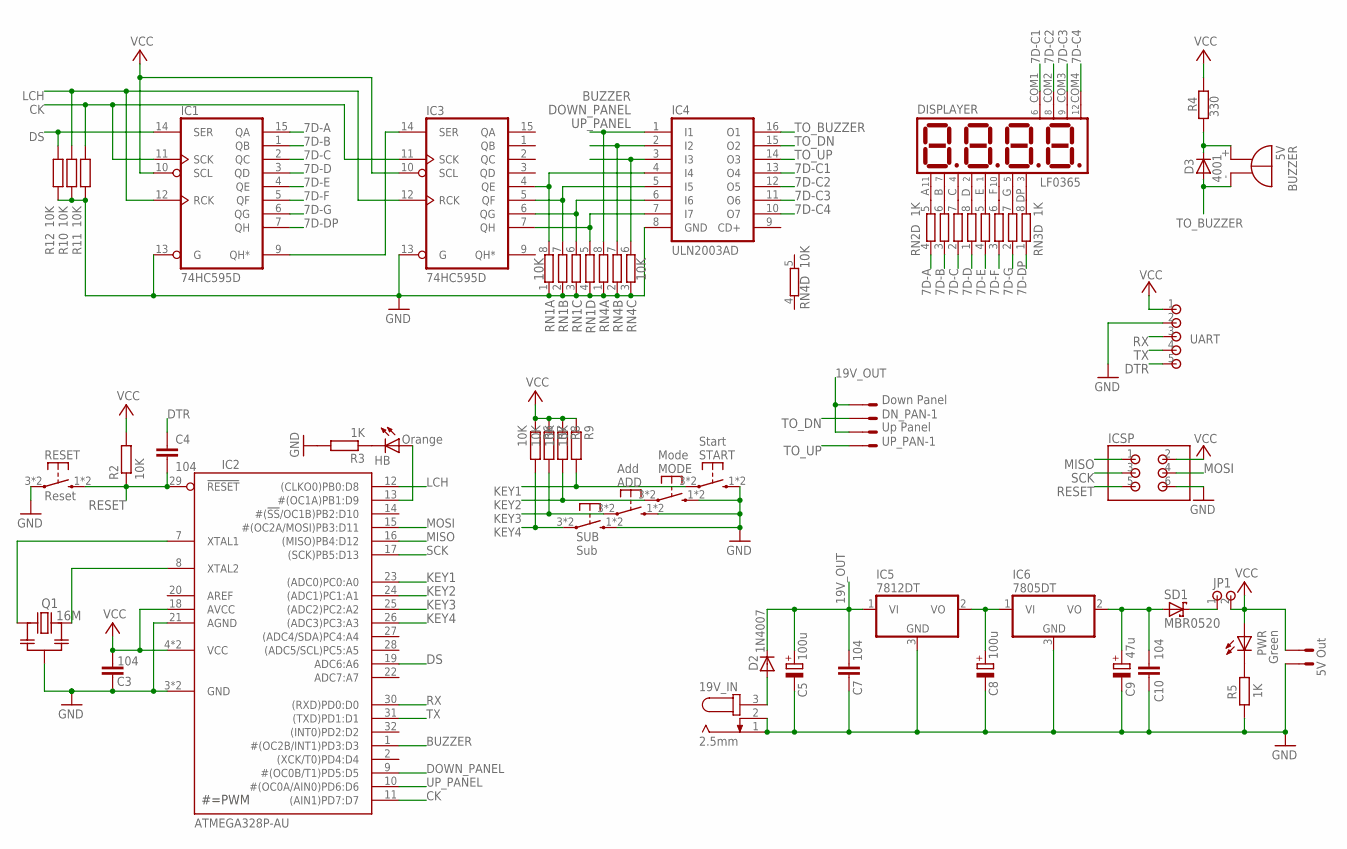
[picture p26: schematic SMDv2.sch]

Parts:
5V_OUT: 5V Out; L02P
19V_IN: 2.5mm; SPC4078
ADD: Add; SW-6*6*3.8MM
BUZZER: 5V; BZ-5V
C3, C4, C7, C10: 104; C0805
C5: 100u; 140CLH-0810
C8: 100u; SMC_C
C9: 47u; SMC_C
D2: 1N4007; DO-214AC
D3: 4001; DO-214AC
DISPLAYER: LF0365; LF036*
DN_PAN: Down Panel; L02P
HB: Orange; CHIPLED_1206
IC1, IC3: 74HC595D; SO16
IC2: ATMEGA328P-AU; TQFP32
IC4: ULN2003AD; SO16
IC5: 7812DT; TO252
IC6: 7805DT; TO252
ICSP: PIN-2X3/DIP; DIP-2.54-2X3
JP1: PIN-1X2-2.54; DIP-2.54-1X2
MODE: Mode; SW-6*6*3.8MM
PWR: Green; CHIPLED_1206
Q1: 16M; CSTCE
R2, R6, R7, R8, R9, R10, R11, R12: 10K; R0805
R3, R5: 1K; R0805
R4: 330; R0805
RESET: Reset; SW-4*4*3.8MM
RN1, RN4: 10K; CAY16
RN2, RN3: 1K; CAY16
SD1: MBR0520; SOD123
START: Start; SW-6*6*3.8MM
SUB: Sub; SW-6*6*3.8MM
UART: PIN-1X5-2.54; DIP-2.54-1X5
UP_PAN: Up Panel; L02P

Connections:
7D-A: IC1.15 (QA), RN2.4 (1)
7D-B: IC1.1 (QB), RN2.3 (1)
7D-C: IC1.2 (QC), RN2.2 (1)
7D-C1: DISPLAYER.COM1, IC4.13 (O4)
7D-C2: DISPLAYER.COM2, IC4.12 (O5)
7D-C3: DISPLAYER.COM3, IC4.11 (O6)
7D-C4: DISPLAYER.COM4, IC4.10 (O7)
7D-D: IC1.3 (QD), RN2.1
7D-DP: IC1.7 (QH), RN3.1
7D-E: IC1.4 (QE), RN3.4 (1)
7D-F: IC1.5 (QF), RN3.3 (1)
7D-G: IC1.6 (QG), RN3.2 (1)
12V: C8.+, IC5.2 (VO), IC6.1 (VI)
19V_OUT: C5.+, C7.1, D2.C, DN_PAN.2, IC5.1 (VI), UP_PAN.2
BUZZER: IC2.1 (#(OC2B/INT1)PD3:D3), IC4.1 (I1), RN4.8 (2)
CK: IC1.11 (SCK), IC2.11 ((AIN1)PD7:D7), IC3.11 (SCK), R11.2
DOWN_PANEL: IC2.9 (#(OC0B/T1)PD5:D5), IC4.2 (I2), RN4.7 (2)
DS: IC1.14 (SER), IC2.19 (ADC6:A6), R12.2
DTR: C4.1, UART.5
GND: 5V_OUT.1, 19V_IN.1, 19V_IN.2, ADD.1 (S), ADD.2 (S), C3.1, C5.-, C7.2, C8.-, C9.-, C10.2, IC1.8 (GND), IC1.13 (G), IC2.3 (GND), IC2.5 (GND), IC2.21 (AGND), IC3.8 (GND), IC3.13 (G), IC4.8 (GND), IC5.3 (GND), IC6.3 (GND), ICSP.6, MODE.1 (S), MODE.2 (S), Q1.2 (GND), R3.2, R5.1, R10.1, R11.1, R12.1, RESET.3, RESET.4, RN1.1, RN1.2 (1), RN1.3 (1), RN1.4 (1), RN4.1, RN4.2 (1), RN4.3 (1), START.1 (S), START.2 (S), SUB.1 (S), SUB.2 (S), UART.2
KEY1: IC2.23 ((ADC0)PC0:A0), R9.2, START.3, START.4
KEY2: IC2.24 ((ADC1)PC1:A1), MODE.3, MODE.4, R8.2
KEY3: ADD.3, ADD.4, IC2.25 ((ADC2)PC2:A2), R7.2
KEY4: IC2.26 ((ADC3)PC3:A3), R6.2, SUB.3, SUB.4
LCH: IC1.12 (RCK), IC2.12 ((CLKO0)PB0:D8), IC3.12 (RCK), R10.2
MISO: IC2.16 ((MISO)PB4:D12), ICSP.1
MOSI: IC2.15 (#(OC2A/MOSI)PB3:D11), ICSP.4
unnamed: 19V_IN.3, D2.A
unnamed: C9.+, C10.1, IC6.2 (VO), SD1.A
unnamed: JP1.1, SD1.K
unnamed: HB.C, R3.1
unnamed: DISPLAYER.A, RN2.5 (2)
unnamed: IC3.4 (QE), IC4.4 (I4), RN1.8 (2)
unnamed: IC2.7 (XTAL1), Q1.1 (IN)
unnamed: PWR.C, R5.2
unnamed: IC1.9 (QH*), IC3.14 (SER)
unnamed: IC3.5 (QF), IC4.5 (I5), RN1.7 (2)
unnamed: DISPLAYER.B, RN2.6 (2)
unnamed: IC3.6 (QG), IC4.6 (I6), RN1.6 (2)
unnamed: IC3.7 (QH), IC4.7 (I7), RN1.5 (2)
unnamed: BUZZER.+, D3.C, R4.1
unnamed: DISPLAYER.C, RN2.7 (2)
unnamed: DISPLAYER.D, RN2.8 (2)
unnamed: DISPLAYER.E, RN3.5 (2)
unnamed: DISPLAYER.F, RN3.6 (2)
unnamed: DISPLAYER.G, RN3.7 (2)
unnamed: DISPLAYER.DP, RN3.8 (2)
unnamed: HB.A, IC2.13 (#(OC1A)PB1:D9)
unnamed: IC2.8 (XTAL2), Q1.3 (OUT)
RESET: C4.2, IC2.29 (!RESET), ICSP.5, R2.1, RESET.1 (S), RESET.2 (S)
RX: IC2.30 ((RXD)PD0:D0), UART.3
SCK: IC2.17 ((SCK)PB5:D13), ICSP.3
TO_BUZZER: BUZZER.-, D3.A, IC4.16 (O1)
TO_DN: DN_PAN.1, IC4.15 (O2)
TO_UP: IC4.14 (O3), UP_PAN.1
TX: IC2.31 ((TXD)PD1:D1), UART.4
UP_PANEL: IC2.10 (#(OC0A/AIN0)PD6:D6), IC4.3 (I3), RN4.6 (2)
VCC: 5V_OUT.2, C3.2, IC1.10 (SCL), IC1.16 (VCC), IC2.4 (VCC), IC2.6 (VCC), IC2.18 (AVCC), IC3.10 (SCL), IC3.16 (VCC), ICSP.2, JP1.2, PWR.A, R2.2, R4.2, R6.1, R7.1, R8.1, R9.1, UART.1

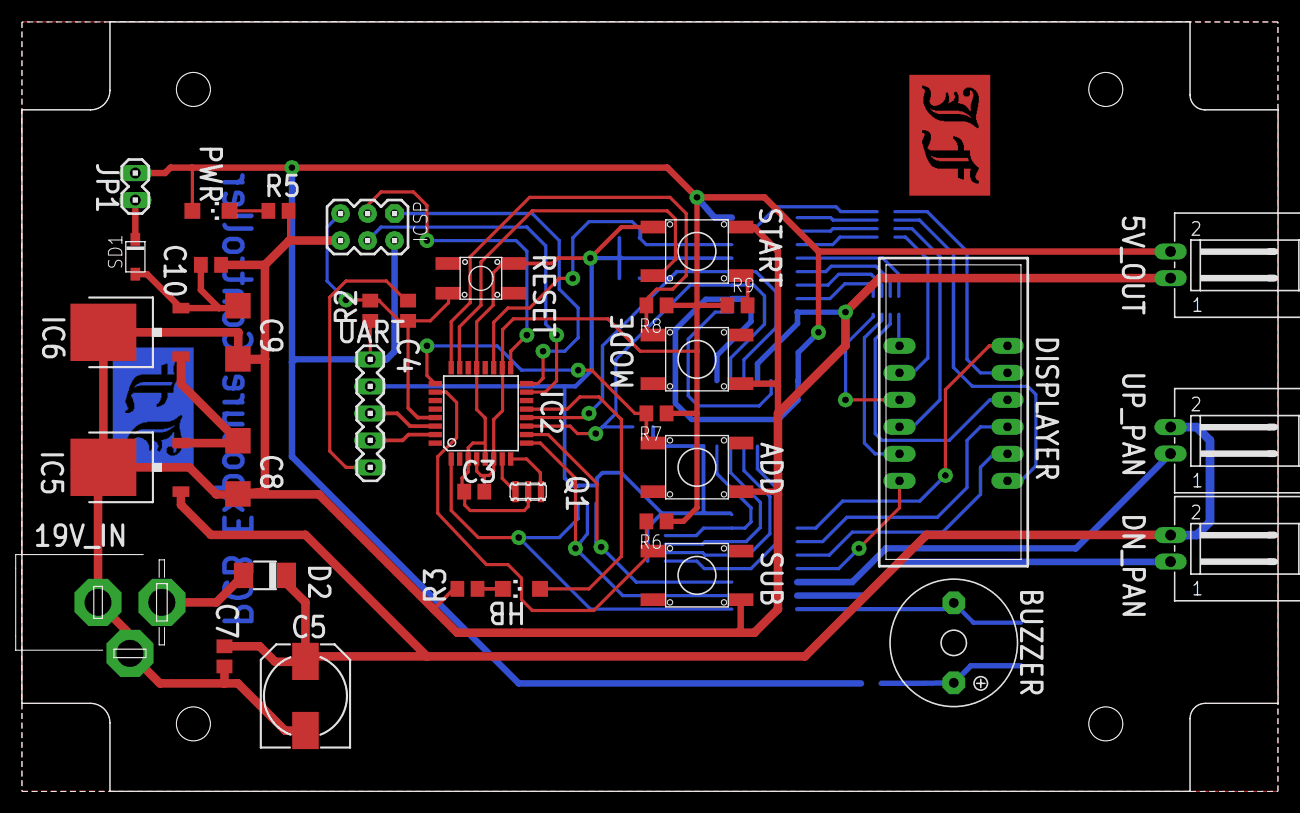
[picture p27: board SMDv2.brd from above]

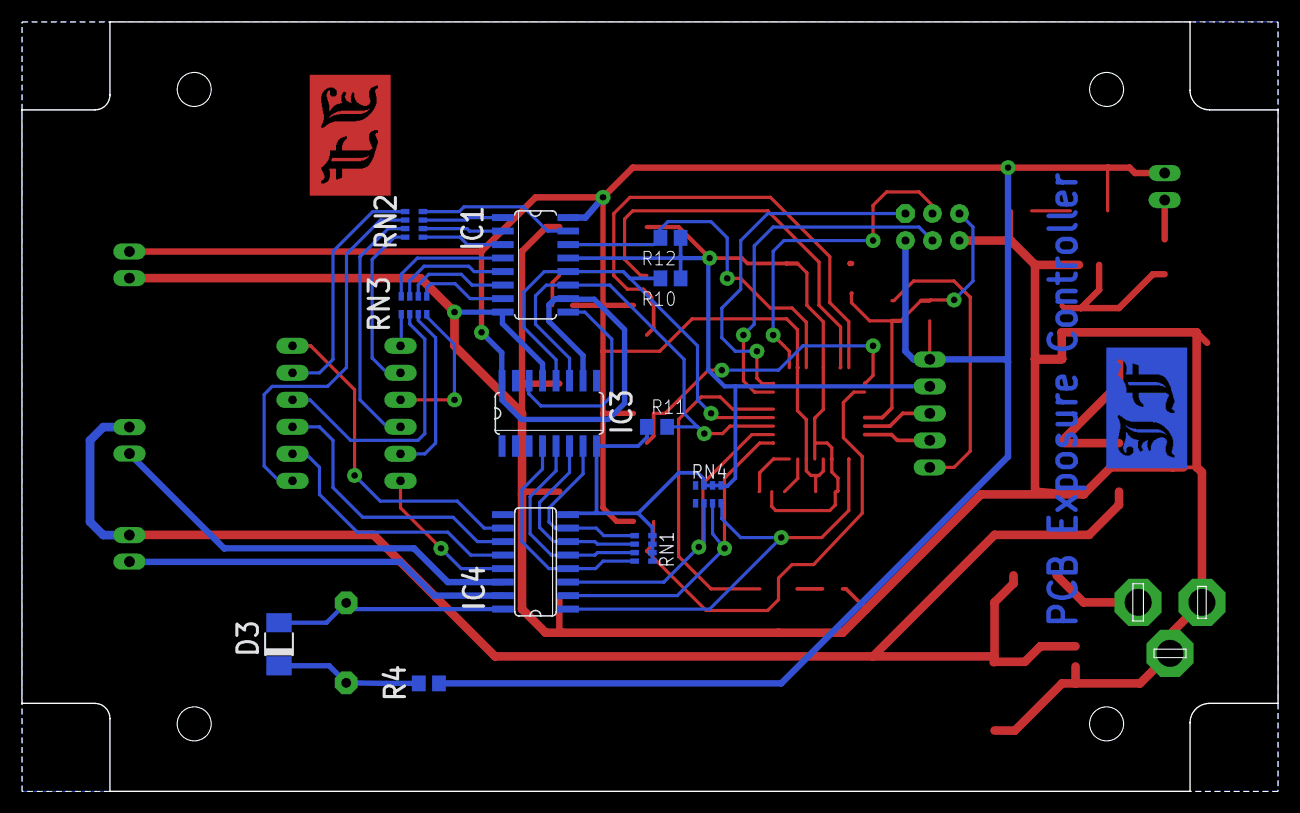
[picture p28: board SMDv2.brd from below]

Board: 2 copper layers, 118.2 x 72.4 mm, 49 parts (12 on the bottom side), 58 nets.

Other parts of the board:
U$1: CASE-1

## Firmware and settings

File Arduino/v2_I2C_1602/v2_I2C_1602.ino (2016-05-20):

/*********************************************
 ** UV 曝光箱控制板 v1.00
 ** Last update : 2016/05/20
 ** 功能概述：
 ** 1. 使用 I2C 溝通界面 Address 為 0x3F(PCF8574A) 
 **    與 HD44780 相容之 LCD1602 作為顯示輸出
 ** 2. 曝光時間最長 900 秒最短 10 秒
 ** 3. 亮度控制最大亮度 100% 最小亮度 5%
 ** 4. 可個別控制上下 UV 亮盤
 ** 5. 使用四個按鍵控制，按鍵各為：開始、模式、+/啟用、-/禁用
 ** 6. 自動模式下，時間終止會播放警示音、閃爍LCD背光以及關閉 UV 亮盤
 ** 7. 手動模式下，使用「開始」鍵開啟與關閉 UV 上下亮盤
 ** 8. 自動記錄前次使用之設定值，避免 Reset 或斷電時需重新設定
 *********************************************/
// ArduinoThread Library
// https://github.com/ivanseidel/ArduinoThread
#include <Thread.h>
#include <ThreadController.h>
// Arduino EEPROMex library
// GitHub : https://github.com/thijse/Arduino-EEPROMEx 
// Anthor Blog : http://thijs.elenbaas.net/2012/07/extended-eeprom-library-for-arduino
#include <EEPROMex.h>
#include <EEPROMVar.h>
// IIC LCD Library
// https://github.com/marcoschwartz/LiquidCrystal_I2C
#include <LiquidCrystal_I2C.h>

// uint8_t = byte = 8bit
#define VERSION  "v1.00"

// 開始鍵 Pin 腳
const uint8_t KEY_START_PIN = A0;
// 模式鍵 Pin 腳
const uint8_t KEY_MODE_PIN = A1;
// 增加鍵 Pin 腳
const uint8_t KEY_ADD_PIN = A2;
// 減少鍵 Pin 腳
const uint8_t KEY_SUB_PIN = A3;
// 蜂鳴器 Pin 腳，僅可使用 PWM
const uint8_t BUZZER_PIN = 3;
// 上層 UV LED 板 Pin 腳，僅可使用 PWM
const uint8_t UP_PANEL_PIN = 5;
// 上層 UV LED 板 Pin 腳，僅可使用 PWM
const uint8_t DN_PANEL_PIN = 6;
// Heartbeat Pin 腳(呼吸燈)
const uint8_t HEARTBEAT_PIN = 9;

// iMode 最大值
const uint8_t MODE_MAX = 4;
// 最大亮度 %
const uint8_t LIGHT_MAX = 100;
// 最小亮度 %
const uint8_t LIGHT_MIN = 5;
// 亮度增減量 %
const uint8_t LIGHT_STEP = 5;
// 曝光最長時間，單位秒
const uint16_t MAX_TIMER = 900;
// 曝光最短時間，單位秒
const uint8_t MIN_TIMER = 10;
// 曝光時間增減量，單位秒
const uint8_t TIMER_ADD_STEP = 10;
// 警告音音頻
const int SOUND_PULSE = 4435;
// EEPROM 開始記錄位置
const int MEM_BASE = 200; 
// EEPROM 最大紀錄長度，單位 Bytes
const int MAX_ALLOW_WRITES = 16;

boolean pressStart = false;     // 是否按下開始鈕
boolean pressMode = false;      // 是否按下模式鈕
boolean pressCount = false;     // 是否按下數字增減鈕
boolean starting = false;       // 是否開始曝光
boolean bCountDown = false;     // 是否正在倒數中
boolean bPlayAlarm = false;     // 是否播放警示音中
uint16_t iCountDown = 120;      // 倒數計數器
uint16_t iStartDown = 0;        // 紀錄開始倒數的秒數
uint8_t iMode = 0;              // 箭頭模式：0時間、1亮度、2上層、3下層、4手動模式
uint8_t iPanel = 3;             // UV燈板顯示模式；0-全不亮、1-上層、2-下層、3-上下層
uint8_t iLight = 80;            // 亮度百分比
uint8_t playIndex = 0;          // 正在播放的聲音順序序號
uint8_t hbval = 128;            // LED 呼吸燈亮度
uint8_t hbdelta = 10;           // 呼吸燈每次增減的值

// EEPROM 讀取值
uint16_t romCountDown = 0;
uint8_t romLight = 0;
uint8_t romPanel = 0;

LiquidCrystal_I2C lcd(0x3F, 16, 2);   // For PCF8574A

// ThreadController that will controll all threads
ThreadController controll = ThreadController();

// Heartbeat Thread
Thread atHeartbeat = Thread();
// Check Button Thread
Thread atCheckButton = Thread();
// Count Down Thread
Thread atCountDown = Thread();
// Alarm Sound Thread
Thread atPlayAlarm = Thread();

// 程式進入點
void setup() {
  Serial.begin(9600);
  while (!Serial);  // 等待 Serial Port 備妥
  SetPinDefine();
  EEPROM.setMemPool(MEM_BASE, EEPROMSizeATmega328);
  EEPROM.setMaxAllowedWrites(MAX_ALLOW_WRITES);
  ReadSettings();
  SetThreads();
  InitializationLCD();
  tone(BUZZER_PIN, SOUND_PULSE);
  delay(100);
  noTone(BUZZER_PIN);
}

// 主迴圈
void loop() {
  controll.run();
}

// 設定 Pin 腳位定義與預設輸出
void SetPinDefine() {
  pinMode(BUZZER_PIN, OUTPUT);
  pinMode(UP_PANEL_PIN, OUTPUT);
  pinMode(DN_PANEL_PIN, OUTPUT);
  pinMode(HEARTBEAT_PIN, OUTPUT);
  pinMode(KEY_START_PIN, INPUT);
  pinMode(KEY_MODE_PIN, INPUT);
  pinMode(KEY_ADD_PIN, INPUT);
  pinMode(KEY_SUB_PIN, INPUT);

  digitalWrite(BUZZER_PIN, LOW);
  digitalWrite(UP_PANEL_PIN, LOW);
  digitalWrite(DN_PANEL_PIN, LOW);
  digitalWrite(HEARTBEAT_PIN, LOW);
  digitalWrite(KEY_START_PIN, LOW);
  digitalWrite(KEY_MODE_PIN, LOW);
  digitalWrite(KEY_ADD_PIN, LOW);
  digitalWrite(KEY_SUB_PIN, LOW);
  digitalWrite(HEARTBEAT_PIN, HIGH);
}

// 設定執行緒
void SetThreads() {
  // Heartbeat Thread
  atHeartbeat.onRun(Heartbeat);
  atHeartbeat.setInterval(50);
  controll.add(&atHeartbeat);

  // Check Button Thread
  atCheckButton.onRun(CheckButtons);
  atCheckButton.setInterval(220);
  controll.add(&atCheckButton);

  // Count Down Thread
  atCountDown.onRun(CountDown);
  atCountDown.setInterval(500);
  controll.add(&atCountDown);
  
  // Alarm Sound Thread
  atPlayAlarm.onRun(PlayAlarm);
  atPlayAlarm.setInterval(100);
  controll.add(&atPlayAlarm);
}

// 顯示測試燈
void Heartbeat() {
  if (hbval <= 20 || hbval >= 240) hbdelta = -hbdelta;
  hbval += hbdelta;
  analogWrite(HEARTBEAT_PIN, hbval);
}

// 倒數計時執行緒
void CountDown() {
  if (!starting || iMode == 4)
    return;
  if (iCountDown > 0) {
    bCountDown = !bCountDown;
    if (!bCountDown) {
      iCountDown--;
      if (iMode != 4)
        ShowTime();
    }
  } else {
    digitalWrite(UP_PANEL_PIN, LOW);
    digitalWrite(DN_PANEL_PIN, LOW);
    starting = false;
    playIndex = 0;
    bPlayAlarm = true;
    bCountDown = false;
  }
}

// 播放警示音
void PlayAlarm() {
  if (!bPlayAlarm)
    return;
  if (playIndex < 7 && playIndex % 2 == 0) {
    tone(BUZZER_PIN, SOUND_PULSE);
    lcd.backlight();
  } else {
    noTone(BUZZER_PIN);
    lcd.noBacklight();
  }
  playIndex++;
  playIndex = playIndex % 10;
}

// 檢查按鍵狀態
void CheckButtons() {
  boolean isPress = HIGH;
  int v = 0;
  isPress = digitalRead(KEY_START_PIN);
  if (!pressStart && isPress == LOW) {  // 按下開始鍵並放開
    if (bPlayAlarm) {
      // 放警示音中
      bPlayAlarm = false;
      playIndex = 0;
      noTone(BUZZER_PIN);
      iCountDown = iStartDown;
      lcd.backlight();
      ShowTime();
      return;
    }
    Serial.print(millis());
    Serial.print(F(" : Press Start, Mode="));
    Serial.println(iMode);
    starting = !starting;
    if (starting) {
      // 閒置中；開始倒數，並依光線強度以 PWM 方式輸出
      iStartDown = iCountDown;
      byte bLight = map(iLight, 0, 100, 0, 255);
      // 控制光盤顯示與否
      if (bitRead(iPanel, 0) != 0)
        analogWrite(UP_PANEL_PIN, bLight);
      else
        digitalWrite(UP_PANEL_PIN, LOW);
      if (bitRead(iPanel, 1) != 0)
        analogWrite(DN_PANEL_PIN, bLight);
      else
          digitalWrite(DN_PANEL_PIN, LOW);
    } else {
      // 倒數中，停止倒數並關閉 UV 光盤
      digitalWrite(UP_PANEL_PIN, LOW);
      digitalWrite(DN_PANEL_PIN, LOW);
    }
    if (iMode == 4) {
      // 手動開始/停止曝光
    } else {
      // 自動開始倒數
      WriteSetting();
      ShowTime();
    }
    pressStart = true;
    return;
  }
  if (pressStart && isPress != LOW) {   // 放開開始鍵時
    pressStart = false;
  }
  if (!starting && !bPlayAlarm) {  
    // 待機中
    isPress = digitalRead(KEY_MODE_PIN);
    if (!pressMode && isPress == LOW) {       // 按下模式鍵
      Serial.print(millis());
      Serial.print(F(" : Press Mode, Original Mode="));
      Serial.print(iMode);
      iMode++;
      if (iMode > MODE_MAX)
        iMode = 0;
      Serial.print(F(", New Mode="));
      Serial.println(iMode);
      pressMode = true;
      if (iMode == 0)
        ShowMenu(1);
      ShowCursor(iMode);
      return;
    }
    if (pressMode && isPress != LOW) {        
      // 放開模式鍵時
      pressMode = false;
    }
    int pressAdd = digitalRead(KEY_ADD_PIN);
    int pressSub = digitalRead(KEY_SUB_PIN);
    if (pressAdd == LOW || pressSub == LOW) { 
      // 按下增加鍵或減少鍵
      Serial.print(millis());
      switch (iMode) {
        case 0:   // 亮盤秒數控制模式
          if (pressSub == LOW) {
            Serial.print(F(" : Press [-] Key, Mode="));
            iCountDown -= TIMER_ADD_STEP;
          } else {
            Serial.print(F(" : Press [+] Key, Mode="));
            iCountDown += TIMER_ADD_STEP;
          }
          Serial.print(iMode);
          Serial.print(F(", New Value="));
          Serial.println(iCountDown);

          if (iCountDown > MAX_TIMER)
            iCountDown = MAX_TIMER;
          else if (iCountDown < MIN_TIMER)
            iCountDown = MIN_TIMER;
          ShowTime();
          break;
        case 1:   // 亮度控制模式
          if (pressSub == LOW) {
            Serial.print(F(" : Press [-] Key, Mode="));
            iLight -= LIGHT_STEP;
          } else {
            Serial.print(F(" : Press [+] Key, Mode="));
            iLight += LIGHT_STEP;
          }
          Serial.println(iMode);
          if (iLight > LIGHT_MAX)
            iLight = LIGHT_MAX;
          else if (iLight < LIGHT_MIN)
            iLight = LIGHT_MIN;
          ShowLight();
          break;
        case 2:   // 上層
          if (pressSub == LOW) {
            Serial.print(F(" : Press [-] Key, Panel="));
            iPanel &= 0xFE;
          } else {
            Serial.print(F(" : Press [+] Key, Panel="));
            iPanel |= 0x01;
          }
          Serial.println(iPanel);
          ShowLedIcons(15);
          break;
        case 3:   // 下層
          if (pressSub == LOW) {
            Serial.print(F(" : Press [-] Key, Panel="));
            iPanel &= 0xFD;
          } else {
            Serial.print(F(" : Press [+] Key, Panel="));
            iPanel |= 0x02;
          }
          Serial.println(iPanel);
          ShowLedIcons(15);
          break;
        case 4:   // 手動模式
          break;
        default:  // 其他未定義
          break;
      }
      pressCount = true;
    }
    if (pressCount && pressAdd != LOW && pressSub != LOW) { 
      // 放開秒數/亮度鍵時 + 鍵
      pressCount = false;
    }
  }
}

// 初始化LCD
void InitializationLCD() {
  lcd.init();
  lcd.clear();
  lcd.noBacklight();
  delay(200);
  for (uint8_t i = 0; i < 3; i++) {
    lcd.backlight();
    delay(100);
    lcd.noBacklight();
    delay(100);
  }
  lcd.backlight(); // finish with backlight on
  lcd.setCursor(0, 0); //Start at character 4 on line 0
  lcd.print(F("Hello, Sir!"));
  delay(500);
  lcd.setCursor(0, 1);
  lcd.print(F("Have a Nice Day!"));
  delay(500);
  SetCustomChar();
  for(int i = 0; i <16; i++) {
    lcd.scrollDisplayLeft();
    delay(100);
  }
  lcd.clear();
  lcd.home();
  lcd.print(F("UV Box - "));
  lcd.print(VERSION);
  delay(2000);
  ShowMenu(0);
}

// 顯示主畫面
void ShowMenu(byte menu) {
  String nv = "";
  switch (menu) {
    case 0:
      lcd.clear();
      ShowCursor(iMode);
    case 1:
      ShowTime();
    case 2:
      ShowLight();
      ShowLedIcons(15);
      break;
    default:
      return;
  }
}

// 顯示倒數時間
void ShowTime() {
  if (iMode == 4)
    return;
  lcd.setCursor(1, 0); //Start at character 4 on line 0
  lcd.print(F("Time :"));
  lcd.print(RightPad(3, iCountDown));
  lcd.print(F("s  "));
}

// 顯示光盤亮度值
void ShowLight() {
  lcd.setCursor(1, 1);
  lcd.print(F("Light:"));
  lcd.print(RightPad(3, iLight));
  lcd.print(F("%  "));
}

// 顯示選單游標
void ShowCursor(byte mode) {
  lcd.setCursor(0, 0);
  lcd.print(F(" "));
  lcd.setCursor(0, 1);
  lcd.print(F(" "));
  lcd.setCursor(14, 0);
  lcd.print(F(" "));
  lcd.setCursor(14, 1);
  lcd.print(F(" "));
  switch (mode) {
    case 0:   // 時間
      lcd.setCursor(0, 0);
      lcd.write(byte(7));
      break;
    case 1:   // 亮度
      lcd.setCursor(0, 1);
      lcd.write(byte(7));
      break;
    case 2:   // 上層
      lcd.setCursor(14, 0);
      lcd.write(byte(7));
      break;
    case 3:   // 下層
      lcd.setCursor(14, 1);
      lcd.write(byte(7));
      break;
    case 4:   // 手動模式
      lcd.setCursor(1, 0); //Start at character 4 on line 0
      lcd.print(F("Time :---"));
      lcd.print(F("s  "));
      break;
    default:
      break;
  }
}

// 將數字轉文字且將之靠右並左補空白
String RightPad(uint8_t len, int val) {
  char nv[4];
  itoa (val, nv, 10);
  String nv1 = String(nv);
  //unsigned int slen = nv1.length();
  uint8_t slen = nv1.length();
  for (uint8_t i = slen + 1; i < 4; i++)
    nv1 = ' ' + nv1;
  return nv1;
}

// 顯示光盤表示明滅的圖示
void ShowLedIcons(uint8_t x) {
  lcd.setCursor(x, 0); //Start at character 4 on line 0
  if (bitRead(iPanel, 0) != 0)
    lcd.write(byte(0));
  else
    lcd.write(byte(1));
  lcd.setCursor(x, 1);
  if (bitRead(iPanel, 1) != 0)
    lcd.write(byte(2));
  else
    lcd.write(byte(3));
}

// 自 EEPROM 中讀取記錄值
void ReadSettings() {
  int sizeByte = sizeof(byte);
  int sizeInt = sizeof(int);
  romCountDown = EEPROM.readInt(MEM_BASE);
  romLight = EEPROM.readByte(MEM_BASE + sizeInt);
  romPanel = EEPROM.readByte(MEM_BASE + sizeInt + sizeByte);
  if (romCountDown > 0)
    iCountDown = romCountDown;
  if (romLight > 0)
    iLight = romLight;
  if (romPanel > 0)
    iPanel = romPanel;  
}

// 儲存記錄值至 EEPROM 中
void WriteSetting() {
  int sizeByte = sizeof(byte);
  int sizeInt = sizeof(int);
  if (romCountDown != iStartDown) {
    romCountDown = iStartDown;
    EEPROM.writeInt(MEM_BASE, romCountDown);
  }
  if (romLight != iLight) {
    romLight = iLight;
    EEPROM.writeByte(MEM_BASE + sizeInt, romLight);
  }
  if (romPanel != iPanel) {
    romPanel = iPanel;
    EEPROM.writeByte(MEM_BASE + sizeInt + sizeByte, romPanel);
  } 
}

// 設定自訂圖示
void SetCustomChar() {
  byte upLightOn[8] = {
    B00000,
    B11111,
    B11111,
    B01110,
    B00000,
    B10101,
    B10101
  };
  byte upLightOff[8] = {
    B00000,
    B11111,
    B10001,
    B01110,
    B00000,
    B00000,
    B00000
  };
  byte dnLightOn[8] = {
    B00000,
    B10101,
    B10101,
    B00000,
    B01110,
    B11111,
    B11111
  };
  byte dnLightOff[8] = {
    B00000,
    B00000,
    B00000,
    B00000,
    B01110,
    B10001,
    B11111
  };
  byte arrow[8] = {
    B00000,
    B11100,
    B01110,
    B00111,
    B01110,
    B11100,
    B00000
  };
  byte none[8] = { };
  lcd.load_custom_character(0, upLightOn);
  lcd.load_custom_character(1, upLightOff);
  lcd.load_custom_character(2, dnLightOn);
  lcd.load_custom_character(3, dnLightOff);
  lcd.load_custom_character(7, arrow);
}

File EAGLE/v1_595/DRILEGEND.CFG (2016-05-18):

InputUserCfg = 1
SymbolLayer = 144
SymbolSize = 40
SymbolWidth = 4
TextSize = 70.0000
TextRatio = 5
IdxFnt = 0
decMM = 2
decMIL = 0
SortHoles = 1
TolPlated = 0.02
TolNonPlated = 0.03
PlatedStatusNot = NOT
PlatedStatusBoth = BOTH
PlatedStatusYes = YES
VerticalChart = 1
HighCellFactor = 1.10
WideCellFactor = 1.10
CellOutline = 4
TitleOutline = 4
TableOutline = 8
SymbTitle = Sym
ToolTitle = N¢X
MMTitle = MM
MilTitle = Mils
MicTitle = Mic
QtyTitle = Qty
TypeTitle = Plated
ToleTitle = Tol
SymbRank = 1
ToolRank = 2
MMRank = 4
MilRank = 3
MicRank = 0
QtyRank = 5
TypeRank = 6
ToleRank = 0
OutputDrillRack = 0
DrillRackFile = DRILLRACK.DRL
Unit = 0
OutputUserCfg = 1
UserCfgFile = DRILEGEND.CFG

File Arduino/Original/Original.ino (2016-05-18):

#include <avr/pgmspace.h>
#include <EEPROM.h>
#include <TimedAction.h>

// Lab12 使用兩顆 74HC595 和三支腳位控制 16 顆 LED
// 接 74HC595 的 SH_CP (pin 11, clock pin)
const int CLOCK_PIN = 10;
// 接 74HC595 的 ST_CP (pin 12,latch pin)
const int LATCH_PIN = 9;
// 接 74HC595 的 DS (pin 14)
const int DATA_PIN = 8;
// 掃描鍵 Pin 腳
const int KEYPAID_PIN = A0;
// 蜂鳴器 Pin 腳，僅可使用 PWM
const int BUZZER_PIN = 3;
// 上層 UV LED 板 Pin 腳，僅可使用 PWM
const int UP_PANEL_PIN = 6;
// 上層 UV LED 板 Pin 腳，僅可使用 PWM
const int DN_PANEL_PIN = 5;
// 心跳 LED Pin 腳
const int HEARTBEAT_PIN = 13;
// 類比按鍵重置鈕 Pin 腳
const int KEY_SCAN_PIN = 4;
// 最大亮度 %
const int LIGHT_MAX = 100;
// 最小亮度 %
const int LIGHT_MIN = 5;
// 亮度增減量 %
const int LIGHT_STEP = 5;
// 曝光最長時間，單位秒
const int MAX_TIMER = 300;
// 曝光最長時間，單位秒
const int MIN_TIMER = 10;
// 曝光時間增減量，單位秒
const int TIMER_ADD_STEP = 10;
// 預設的按鍵值
const int DEF_KEY_CODE[8] PROGMEM = { 
  825, 820, 618, 614, 410, 406, 205, 201 };
// 警告音音頻
const int SOUND_PULSE = 4435;

int kv[8] = { 
  0, 0, 0, 0, 0, 0, 0, 0 };

boolean pressStart = false;
boolean pressMode = false;
boolean pressCount = false;
boolean starting = false;      // 是否開始曝光
boolean bHeartbeat = false;
boolean playAlert = false;
boolean bBlink = false;
boolean scanMode = false;
boolean scanStart = false;
boolean onEvasive = false;

int iCountDown = 10;           // 預設開始秒數
int iStartDown = 0;
int iMode = 2;                 // 預設模式，上下層
int iLight = 50;               // 亮度百分比
int scanKeyPressTime = 0;
int scanKeyNo = 0;
int scanTimer = 0;
int scanValue = 0;
int scanMax = 0;
int scanMin = 1023;
int evasiveCount = 0;
int playIndex = 0;

const byte LEDs[11] = {
  B00111111,  // 0, pgfedcba
  B00000110,  // 1
  B01011011,  // 2
  B01001111,  // 3
  B01100110,  // 4
  B01101101,  // 5
  B01111101,  // 6
  B00100111,  // 7
  B01111111,  // 8
  B01101111,  // 9
  B01110011   // P
};
const byte MODEs[4] = {
  B00000001,   // 上標線, 亮上光盤
  B00001000,   // 下標線, 亮下光盤
  B00001001,   // 上下標線, 亮上下兩光盤
  B01001001    // 上下標線加減號(-), 亮度設定模式
};

TimedAction taBlink = TimedAction(500, Blink);
TimedAction taHeartbeat = TimedAction(500, Heartbeat);
TimedAction taCheckButton = TimedAction(200, CheckButtons);
TimedAction taPlayAlert = TimedAction(100, PlayAlert);
TimedAction taShowCountDown = TimedAction(1, ShowCountDown);
TimedAction taEvasiveKeyCode = TimedAction(1, EvasiveKeyCode);
TimedAction taShowSoundPulse = TimedAction(1, ShowSoundPulse);


void setup() {
  Serial.begin(9600);
  ReadKeyCodes();
  // 將 LATCH_PIN, CLOCK_PIN, DATA_PIN 設置為輸出
  pinMode(LATCH_PIN, OUTPUT);
  pinMode(CLOCK_PIN, OUTPUT);
  pinMode(DATA_PIN, OUTPUT);
  pinMode(BUZZER_PIN, OUTPUT);
  pinMode(HEARTBEAT_PIN, OUTPUT);
  pinMode(UP_PANEL_PIN, OUTPUT);
  digitalWrite(UP_PANEL_PIN, LOW);
  pinMode(DN_PANEL_PIN, OUTPUT);
  digitalWrite(DN_PANEL_PIN, LOW);
  pinMode(KEYPAID_PIN, INPUT);
  digitalWrite(KEYPAID_PIN, LOW);
  taHeartbeat.disable();
  taEvasiveKeyCode.disable();
  taPlayAlert.disable();
}

void loop() {
  taBlink.check();
  if (!onEvasive)
    taCheckButton.check();
  taHeartbeat.check();
  if (!scanMode)
    taShowCountDown.check();
  else {
    if (onEvasive)
      taEvasiveKeyCode.check();
    else {
      if (!scanStart)
        ShowScanKeyNo();
      else
        ShowNumber(scanValue);
    }
  }
  taPlayAlert.check();
}
void ReadKeyCodes() {
  int i = 0;
  int idx = 0;
  int v = 0;
  byte bh = 0;
  byte bl = 0;
  for (i = 0; i < 16; i += 2) {
    bh = EEPROM.read(i);
    bl = EEPROM.read(i + 1);
    idx = (i + 1) / 2;
    if (bh == 0xFF) {
      v = pgm_read_word(&DEF_KEY_CODE[idx]);
      kv[idx] = v;
      EEPROM.write(i, kv[idx] / 256);
      EEPROM.write(i + 1, kv[idx] % 256);
    } 
    else {
      kv[idx] = bh * 256 + bl;
    }
  }
}
void SaveKeyCodes() {
  int idx = 0;
  int i = 0;
  for (i = 0; i < 16; i += 2) {
    idx = (i + 1) / 2;
    EEPROM.write(i, kv[idx] / 256);
    EEPROM.write(i + 1, kv[idx] % 256);
  }
}
void Blink() {
  bBlink = !bBlink;
  digitalWrite(HEARTBEAT_PIN, (bBlink) ? HIGH : LOW);
}
void Heartbeat() {
  if (starting) {
    if (iCountDown > 0) {
      bHeartbeat = !bHeartbeat;
      Serial.println(iCountDown);
      if (!bHeartbeat)
        iCountDown--;
    }
    else 
    {
      digitalWrite(UP_PANEL_PIN, LOW);
      digitalWrite(DN_PANEL_PIN, LOW);
      starting = false;
      playIndex = 0;
      taPlayAlert.enable();
      playAlert = true;
      bHeartbeat = false;      
    }
  }
}
void CheckButtons() {
  int val = 0;
  int v = 0;
  if (!scanMode) {
    boolean scanKeyDown = digitalRead(KEY_SCAN_PIN);
    if (scanKeyDown) {
      if (scanKeyPressTime == 0)
        scanKeyPressTime = millis();
      else {
        v = millis();
        if (v - scanKeyPressTime >= 3000) {
          scanStart = false;
          scanKeyNo = 0;
          scanMode = true;
          scanKeyPressTime = 0;
          ReadKeyCodes();
          return;
        }
      }
    }
    else {
      scanKeyPressTime = 0;
    }
  } 
  else {
    val = analogRead(KEYPAID_PIN);
    if (!scanStart) {
      if (val > 50) {
        scanTimer = millis();
        scanStart = true;      
        scanValue = val;
        scanMax = val;
        scanMin = val;
      } 
      else {
        scanStart = false;
        scanTimer = 0;
      }
    } 
    else {
      int now = millis();
      scanValue = val;
      if (now - scanTimer >= 1500) {
        scanMax = max(scanMax, val);
        scanMin = min(scanMin, val);
      }
      if (now - scanTimer >= 5000) {
        kv[scanKeyNo * 2] = scanMax + 2;
        kv[scanKeyNo * 2 + 1] = scanMin - 2;
        taEvasiveKeyCode.enable();
        EvasiveKeyCode();
      }
    } 
    return;
  }
  val = analogRead(KEYPAID_PIN);
  if (!starting && !playAlert) {
    if (!pressMode && val >= kv[5] && val <= kv[4]) {
      iMode++;
      if (iMode >= 4) 
        iMode = 0;
      pressMode = true;
    }
    // 放開模式鍵時
    if (pressMode && (val < kv[5] || val > kv[4]))
      pressMode = false;
    if (!pressCount && ((val >= kv[1] && val <= kv[0]) || (val >= kv[3] && val <= kv[2]))) {
      if (iMode != 3) {
        if ((val >= kv[1] && val <= kv[0]))
          iCountDown -= TIMER_ADD_STEP;
        else
          iCountDown += TIMER_ADD_STEP;
        if (iCountDown > MAX_TIMER) 
          iCountDown = MIN_TIMER;
        else if (iCountDown <= 0)
          iCountDown = MAX_TIMER;
      }
      else {
        if ((val >= kv[1] && val <= kv[0]))
          iLight -= LIGHT_STEP;
        else
          iLight += LIGHT_STEP;
        if (iLight > LIGHT_MAX)
          iLight = LIGHT_MIN;
        else if (iLight <= 0)
          iLight = LIGHT_MAX;
      }
      pressCount = true;
    }
    // 放開秒數/亮度鍵時 + 鍵
    if (pressCount && (val < kv[1] || (val > kv[0] && val < kv[3]) || val > kv[2]))
      pressCount = false;
  }  
  if (iMode != 3) {
    if (!pressStart && val >= kv[7] && val <= kv[6]) {
      if (iCountDown > 0) {
        starting = !starting;
        iStartDown = iCountDown;
        if (starting) {
          taHeartbeat.enable();
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

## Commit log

2016-05-18 完成 v1.00
2016-05-20 無關緊要的小修改
2016-05-20 小調整啟動時LCD的流程
2016-07-21 新增直接使用 LCD 結合母版的方式
    [UVBox-I2C.brd, UVBox-I2C_LCD.brd, UVBox-I2C_LCD.sch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]
2016-08-02 細微修改
    [UVBox-I2C_LCD.brd]
2017-12-28 增加本說明文件
2018-01-15 刪除舊Gerber
2018-01-16 調整線路配置
    [UVBox-I2C_LCD.brd, UVBox-I2C_LCD.sch]
2018-01-16 調整絲印字型大小
    [UVBox-I2C_LCD.brd]
2018-01-25 更換零件與微調線路
    [UVBox-I2C_LCD.brd, UVBox-I2C_LCD.sch]
